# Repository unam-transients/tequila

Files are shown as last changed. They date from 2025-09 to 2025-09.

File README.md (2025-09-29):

# TEQUILA

TEQUILA (Transient Event *Q*, *U*, and *I* Light Analyzer) is an innovative imaging polarimeter being developed for the second Nasmyth port of COLIBRÍ. The science goals include measuring the evolution of the polarization of the optical afterglow of GRBs and variability in the polarization of blazars.

The project is lead by [Noémie Globus](https://github.com/orgs/unam-transients/people/mahadanah) with technical assistance from [Alan Watson](https://github.com/orgs/unam-transients/people/alanwatsonatwork).

- [Issues](https://github.com/orgs/unam-transients/projects/8)
- Repositories:
  - [sangrita](https://github.com/unam-transients/sangrita)
  - [tcs](https://github.com/unam-transients/tcs)
  - [tequila](https://github.com/unam-transients/tequila)
  - [tequila-science-and-design](https://github.com/unam-transients/tequila-science-and-design)

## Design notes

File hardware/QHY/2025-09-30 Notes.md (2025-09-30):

# 2029-09-30 Notes

Alan (CU) and Noémie (Ensenada)

- Noémie connected the external power supply.
- Initially, Alan was only able to cool to about -2 C, however the airflow was impeded. With the airflow free, he was able to cool it to about -6 C.
- With no cooling but with the fan, the temperature is about 32 C. The previous day, without the fans, it was about 45 C.
- Noémie disconnected the camera and RPi as they were too hot. Her office is at about 30 C.

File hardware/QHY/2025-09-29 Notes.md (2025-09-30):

# 2025-09-29 Notes

Alan (CU) and Noémie (Ensenada) working with the RPi and the QHY sensor.

## USB Capacity

We had the USB flash drive connected to the blue USB3 bus. Whenever we connected the QHY sensor to the blue bus we had problems with the RPi. Specifically, Alan was no longer able to run command, and we were not able to connect by SSH. Alan suspects the current drawn by the QHY was sufficient that the USB memory no longer worked. We apparently fixed this by connecting the USB memory to the white USB2 bus.

We then connected an external USB hard drive to the RPi via the white USB2 bus. It was seen initially, but then was not visible to `fdisk -l`. Alan rebooted the RPi, and it did not come back up. After removing the hard disk, it came back without any problem.

The conclusion seems to be:
- The QHY camera cannot share the USB3 bus with the USB flash memory.
- The USB flash memory cannot share the USB2 bus with USB hard drive.

## Control

I was able to:

- Determine the identifiers of the connected cameras.
- Open the camera by identifier.
- Determine its format.
- Read the temperature and cooler power.
- Read a FITS file.

I was not able to cool it as the external power supply was not connected.

## Documentation

The manual seems to be incomplete. It seems best to read it in conjunction with the header files.

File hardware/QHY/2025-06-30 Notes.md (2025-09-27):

# 2025-06-30 Laboratory Session

Noémie, Alan

Noémie had the new QHY 1253P sensor package.

The sensor was not supplied with a power supply. There was an extension that ended in a car adapter. With David’s intervention, someone connected the car adapter to a 12V power supply using crocodile clips.
Noémie installed QHY’s EZCAP software on her Mac.

We opened the sensor. We set the TEC to 50% manually. The power supply read 0.83 A. Stabilized at -3.7 C. The ambient temperature was about 23 C.

We took images with different gains, and that seemed to work. This is our first-light image:

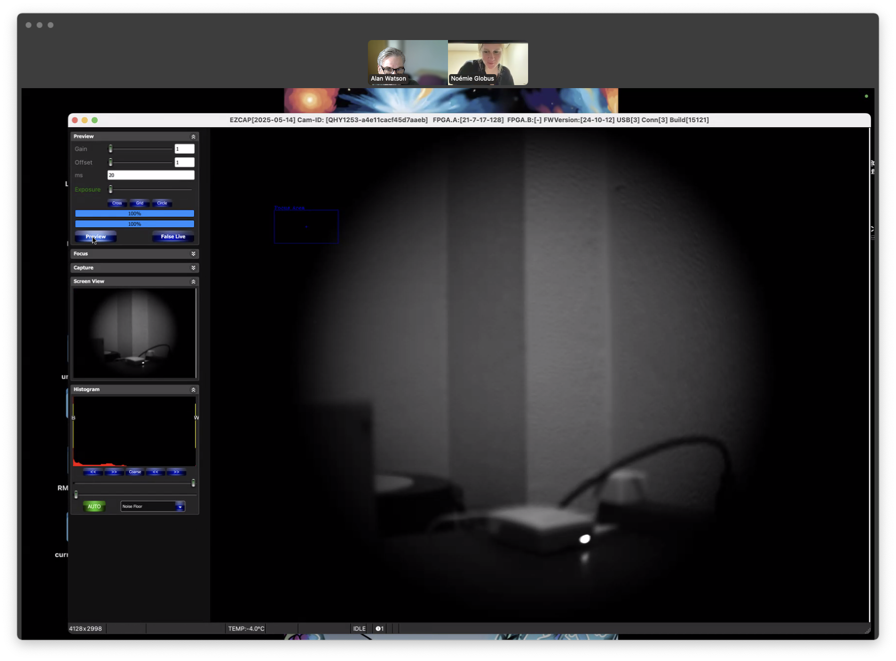
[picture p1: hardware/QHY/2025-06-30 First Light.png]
First-light image with the TEQUILA sensor First Light


We were able to set the temperature set point.

With TEC at 100%, the power supply read 1.67 A and the detector stabilized at -14.1 C.

We connected to the RPi. The sensor showed up as a “Cypress WestBridge”.

The housing has a ventilator.

We turned off the 12 V supply, but the sensor still appeared on the USB bus on the RPi.

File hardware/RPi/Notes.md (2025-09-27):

# Notes

2025-06-16: Alan sent Noémie a RPi 4 with 2 GB RB, 32 GB USB flash storage, and RPi USB-C power supply. The computer is on the UNAM Transients Tailscale VPN as "tequila-detector". It runs Ubuntu 24.04 LTS server.

2025-09-24: Alan gave Noémie a 1 TB external hard disk.

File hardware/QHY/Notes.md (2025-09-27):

# Notes

2025-05-23: Noémie ordered the detector using SCEECS funds at Stanford.

2025-06-17: Alan sent a Tamron 12VM1040ASIR 10-40 mm C-mount lens for the initial tests of the sensor.

2025-06-27: Noémie picked up the detector in LA.

2025-06-30: First light in the laboratory in Ensenada, running the QHY software on Noémie's Mac. Noémie was in the lab and Alan was on Zoom.

2025-06-30: Noémie bought a power supply from Amazon.

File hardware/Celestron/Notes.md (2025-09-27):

# Notes

Alan took one of the DDOTI adapters on 2025-09-23. It is currently in Mexico City. He has verified that it threads into the Edmund Optics T-mount separators.

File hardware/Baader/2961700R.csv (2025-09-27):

Baader SLOAN/SDSS r' Filter
λ (nm) | OD
200 | 7.404829948
201 | 6.487751797
202 | 6.695987374
203 | 7.385212657
204 | 7.253948757
205 | 7.143584362
206 | 6.735293259
207 | 6.944553319
208 | 6.797151173
209 | 7.076483743
210 | 6.867747845
211 | 7.202849989
212 | 6.919806970
213 | 7.006161490
214 | 6.950086375
215 | 6.819588336
216 | 6.937823771
217 | 7.101651772
218 | 6.793304495
219 | 7.013749629
220 | 7.234964484
221 | 6.895943519
222 | 6.952961717
223 | 6.993506486
224 | 7.009439787
225 | 6.943001524
226 | 6.986196389
227 | 6.937673117
228 | 7.035574262
229 | 7.124405156
230 | 6.837262205
231 | 6.933515886
232 | 6.949678127
233 | 7.054954803
234 | 6.914971177
235 | 7.134106375
236 | 7.035253280
237 | 6.855648408
238 | 6.903677095
239 | 7.026127530
240 | 7.037190999
241 | 6.995930179
242 | 6.940552731
243 | 7.073450381
244 | 6.975485587
245 | 7.025657044
246 | 7.000277144
247 | 6.953369057
248 | 7.009998378
249 | 7.190752040
250 | 7.058660273
251 | 6.967846107
252 | 6.937626206
253 | 7.127089643
254 | 6.897318147
255 | 7.002483836
256 | 6.921268666
257 | 7.187517399
258 | 6.982351557
259 | 6.927545176
260 | 6.996768497
261 | 7.022745706
262 | 7.000779786
263 | 6.960268142
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

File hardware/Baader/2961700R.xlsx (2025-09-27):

Baader SLOAN/SDSS r' Filter
l (nm) | OD
200 | 7.404829948
201 | 6.487751797
202 | 6.695987374
203 | 7.385212657
204 | 7.253948757
205 | 7.143584362
206 | 6.735293259
207 | 6.944553319
208 | 6.797151173
209 | 7.076483743
210 | 6.867747845
211 | 7.202849989
212 | 6.919806970
213 | 7.006161490
214 | 6.950086375
215 | 6.819588336
216 | 6.937823771
217 | 7.101651772
218 | 6.793304495
219 | 7.013749629
220 | 7.234964484
221 | 6.895943519
222 | 6.952961717
223 | 6.993506486
224 | 7.009439787
225 | 6.943001524
226 | 6.986196389
227 | 6.937673117
228 | 7.035574262
229 | 7.124405156
230 | 6.837262205
231 | 6.933515886
232 | 6.949678127
233 | 7.054954803
234 | 6.914971177
235 | 7.134106375
236 | 7.035253280
237 | 6.855648408
238 | 6.903677095
239 | 7.026127530
240 | 7.037190999
241 | 6.995930179
242 | 6.940552731
243 | 7.073450381
244 | 6.975485587
245 | 7.025657044
246 | 7.000277144
247 | 6.953369057
248 | 7.009998378
249 | 7.190752040
250 | 7.058660273
251 | 6.967846107
252 | 6.937626206
253 | 7.127089643
254 | 6.897318147
255 | 7.002483836
256 | 6.921268666
257 | 7.187517399
258 | 6.982351557
259 | 6.927545176
260 | 6.996768497
261 | 7.022745706
262 | 7.000779786
263 | 6.960268142
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

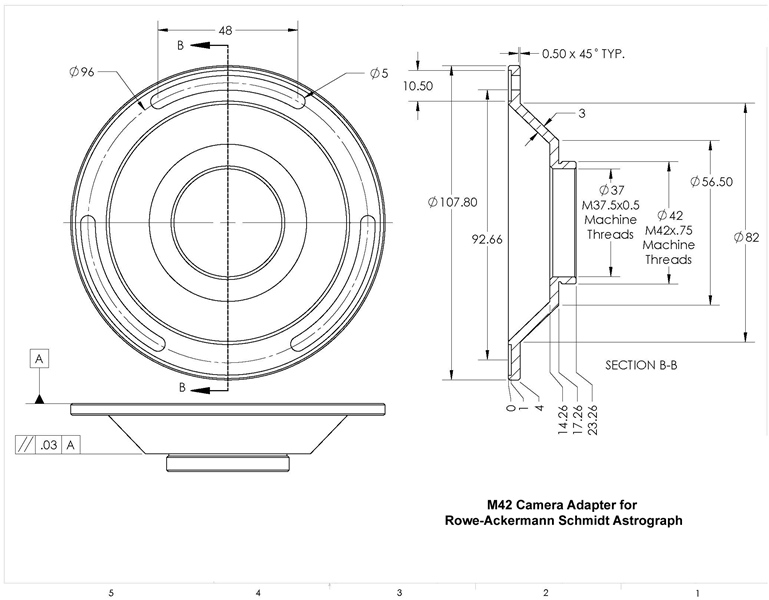
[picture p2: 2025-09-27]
hardware/Celestron/celestron-rasa-to-t-adapter.jpg

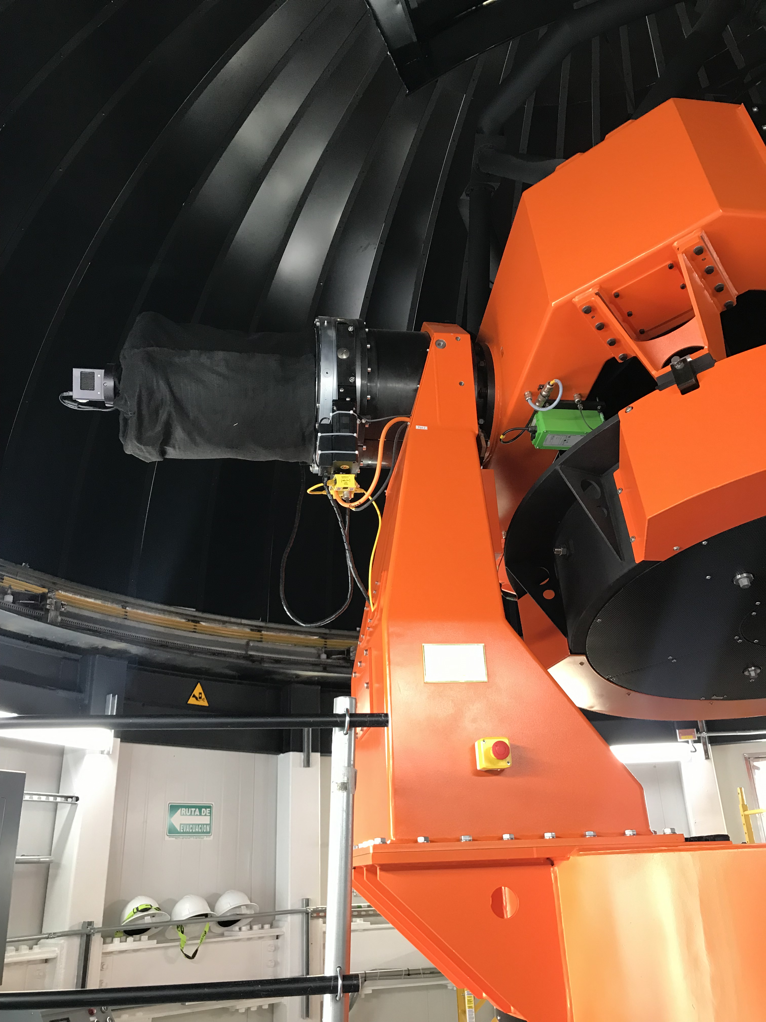
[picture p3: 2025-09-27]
hardware/OGSE/2025-09-23 OGSE.jpg

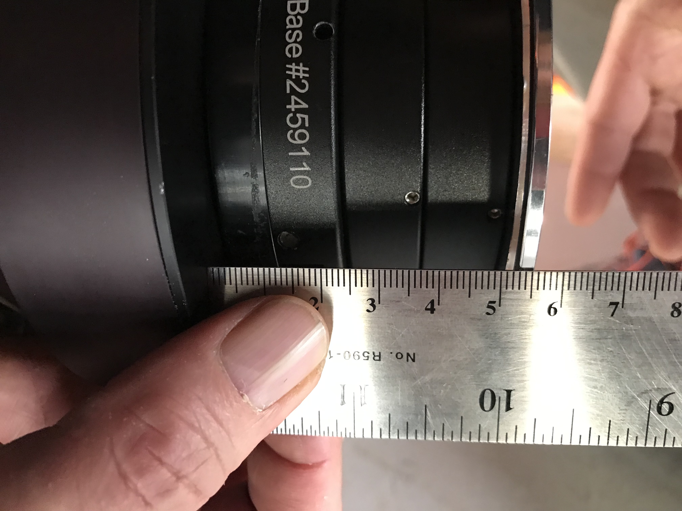
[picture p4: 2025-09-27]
hardware/OGSE/2025-09-23 OGSE FLI detector extension.jpg

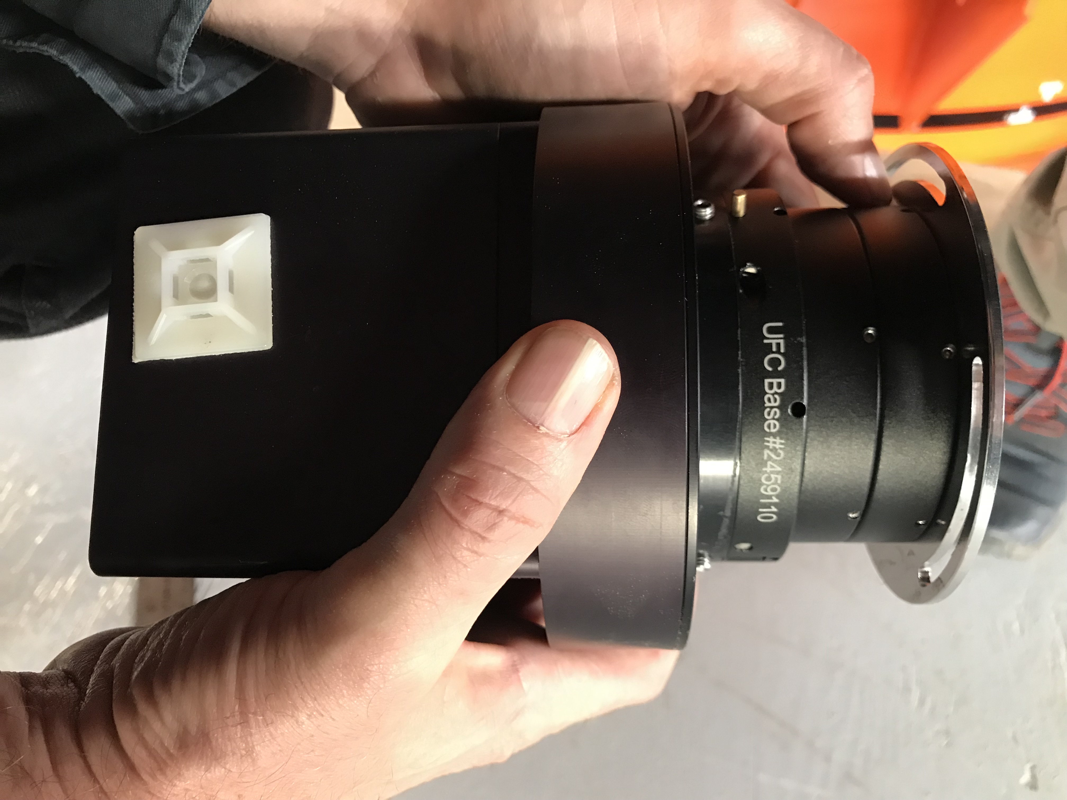
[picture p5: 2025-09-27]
hardware/OGSE/2025-09-23 OGSE FLI detector.jpg

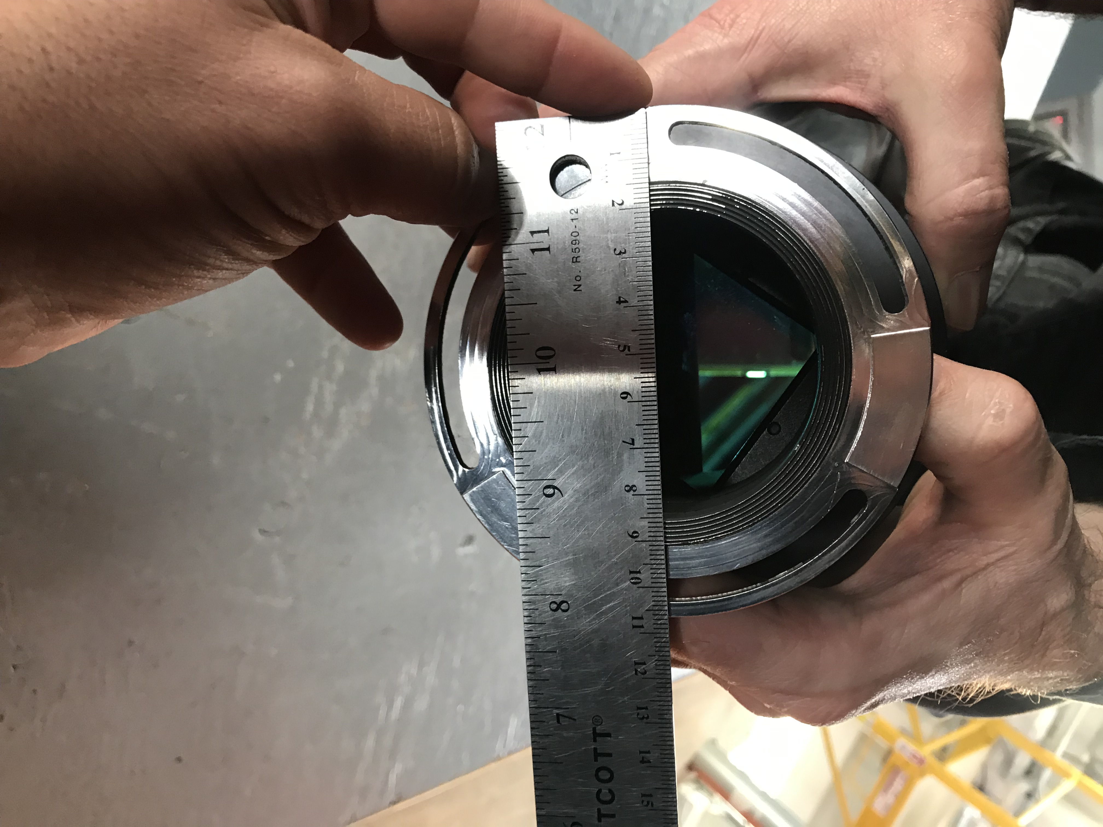
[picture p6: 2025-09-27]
hardware/OGSE/2025-09-23 OGSE FLI detector aperture.jpg

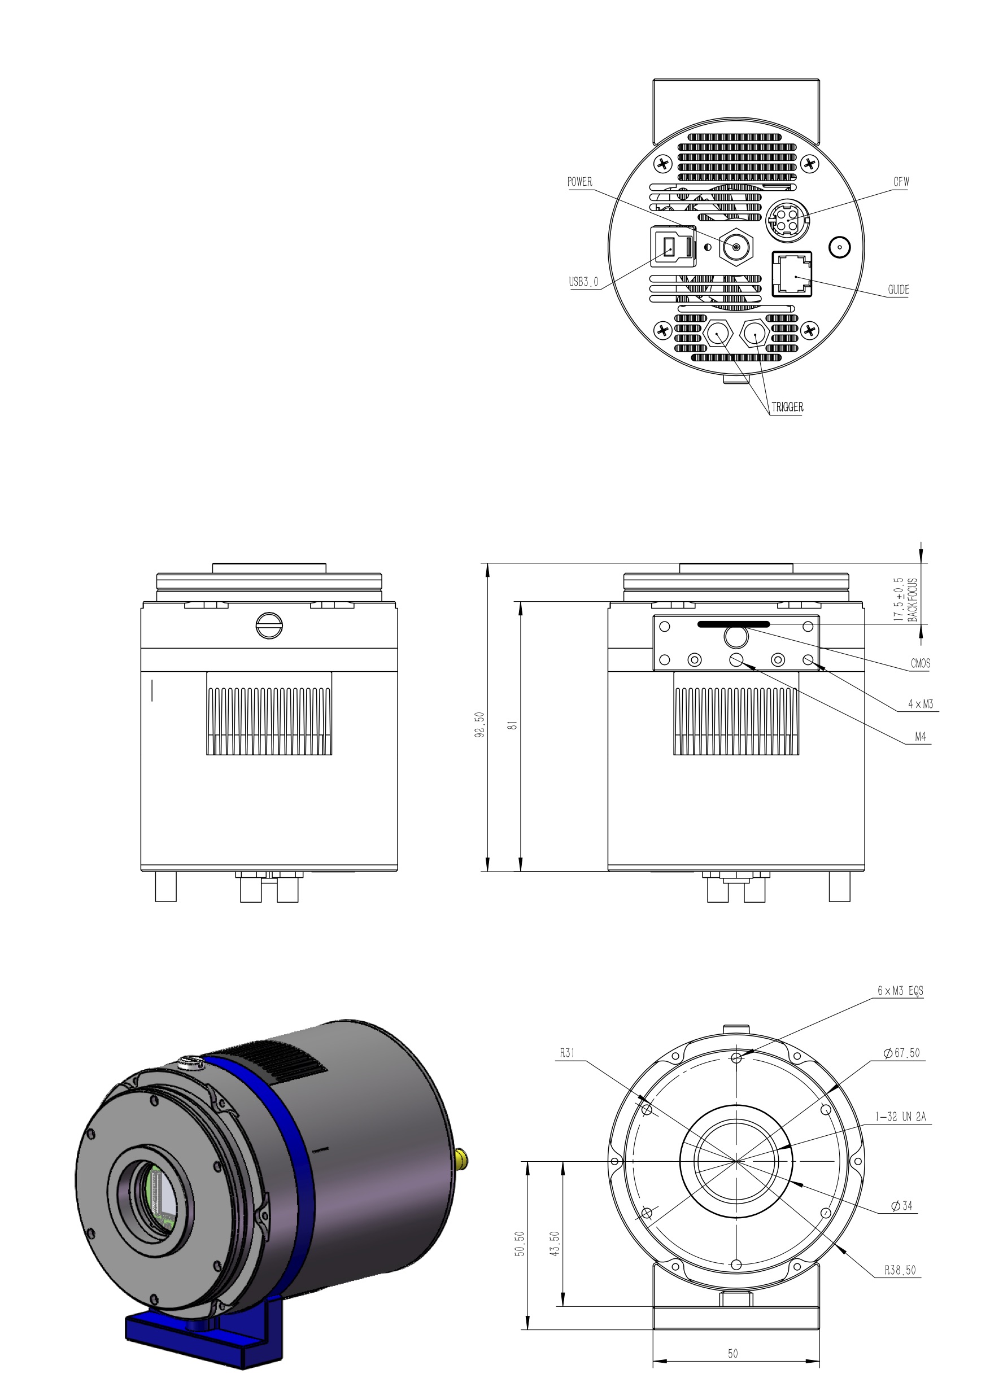
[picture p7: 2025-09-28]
hardware/QHY/QHY 1253P Mechanical Drawings.jpg

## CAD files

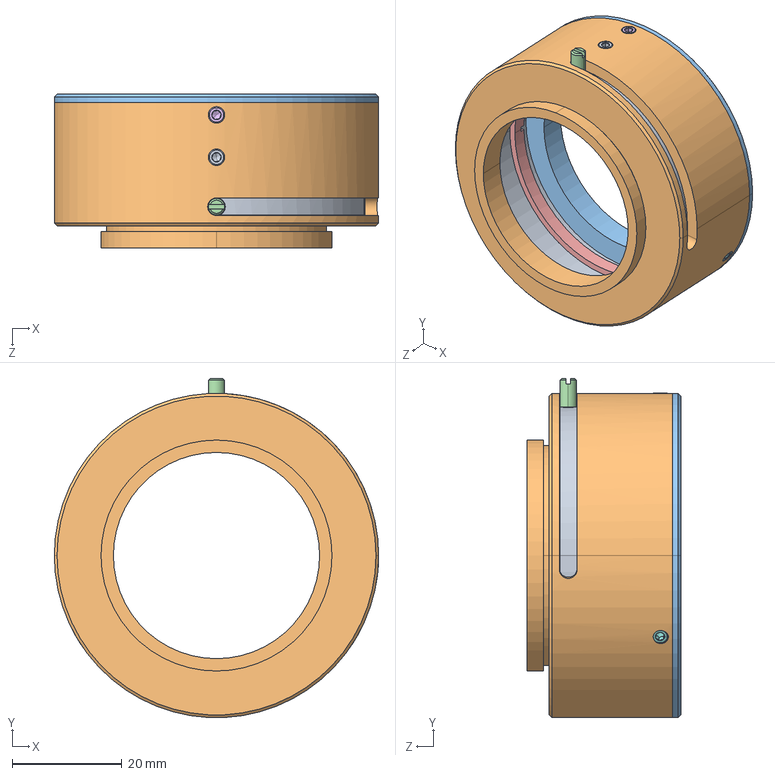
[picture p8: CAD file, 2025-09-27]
hardware/Edmund Optics/11147/step_11147.step
59.0 x 61.7 x 28.0 mm

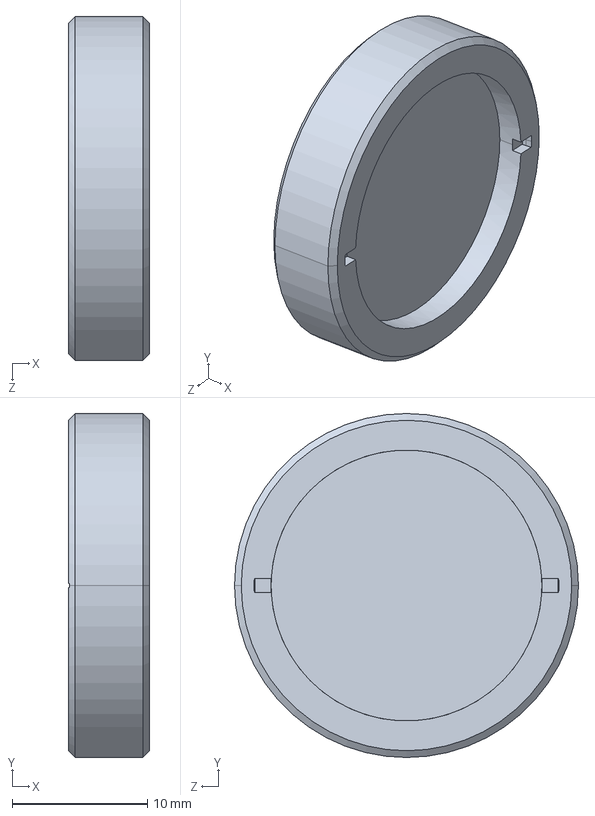
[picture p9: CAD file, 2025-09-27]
hardware/Edmund Optics/39038/step_39038.step
6.00 x 25.4 x 25.4 mm

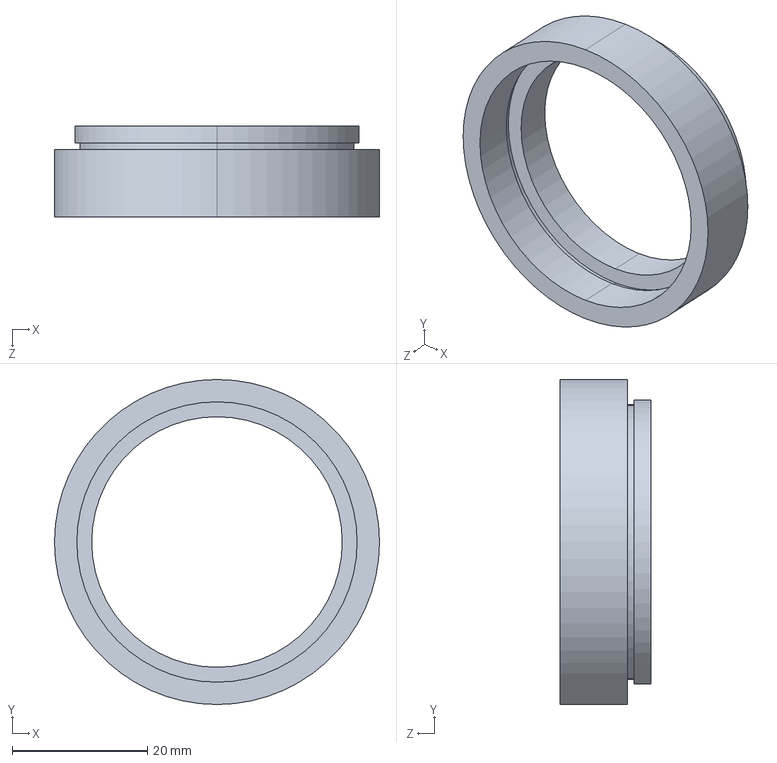
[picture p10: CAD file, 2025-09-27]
hardware/Edmund Optics/52294/step_52294.step
48.0 x 48.0 x 13.5 mm

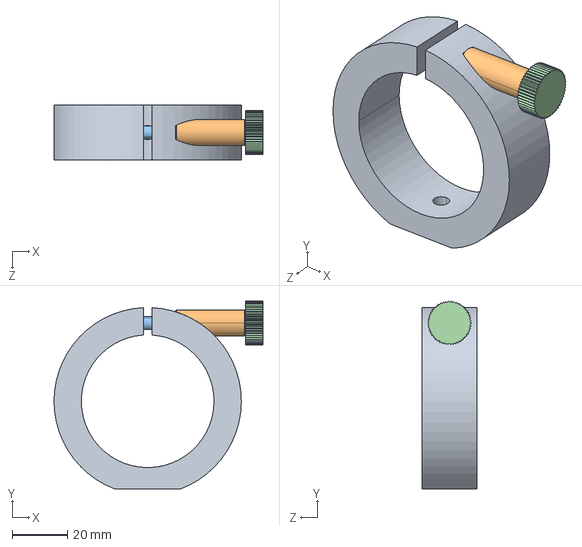
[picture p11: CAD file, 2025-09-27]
hardware/Edmund Optics/52304/step_52304.step
75.8 x 68.2 x 19.9 mm

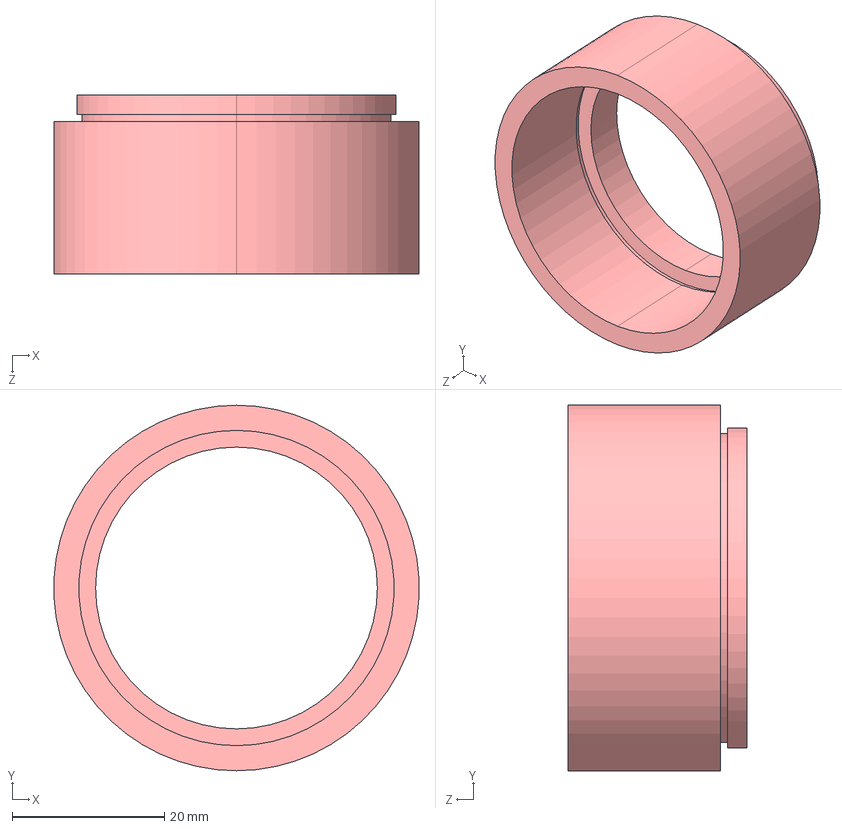
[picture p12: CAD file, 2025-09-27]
hardware/Edmund Optics/53231/iges_53231.igs
47.9 x 48.0 x 23.5 mm

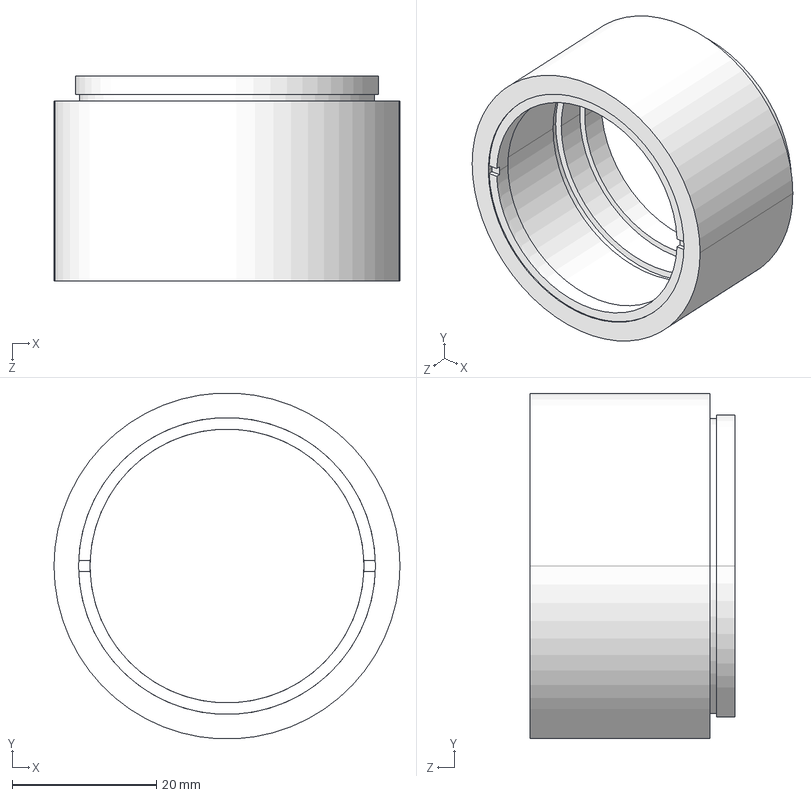
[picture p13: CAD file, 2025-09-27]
hardware/Edmund Optics/57978/iges_57978.igs
48.0 x 47.9 x 28.5 mm

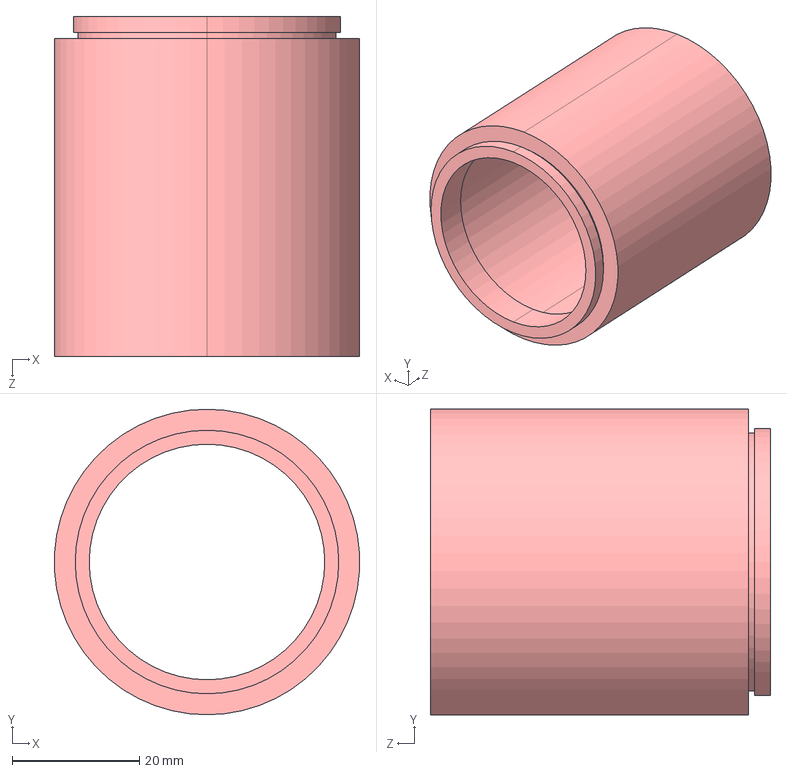
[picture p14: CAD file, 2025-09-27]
hardware/Edmund Optics/58735/iges_58735.igs
47.9 x 48.0 x 53.5 mm

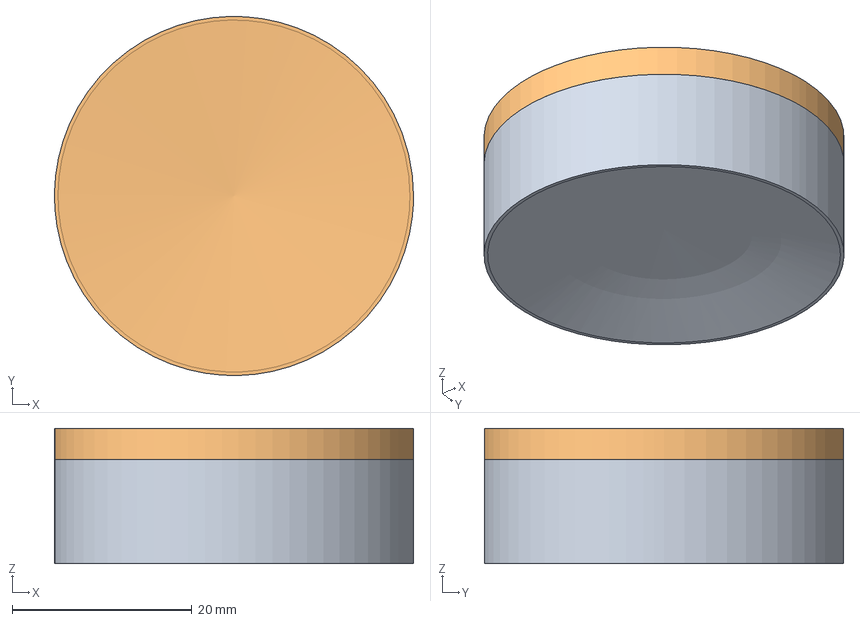
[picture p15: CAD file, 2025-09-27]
hardware/Edmund Optics/63765/iges_63765.igs
40.0 x 40.0 x 15.1 mm

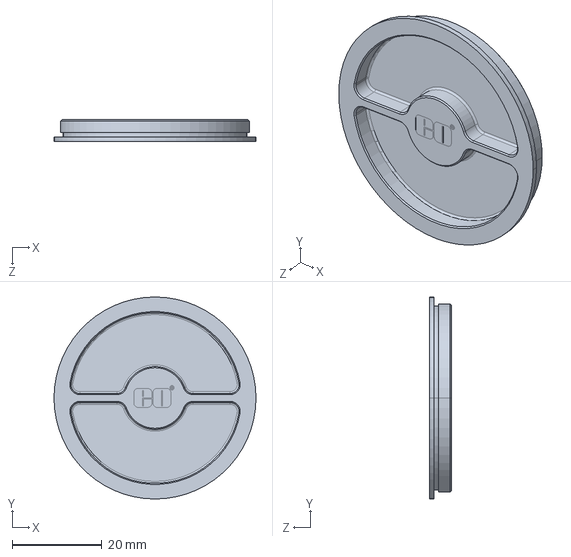
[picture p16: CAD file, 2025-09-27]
hardware/Edmund Optics/66037/step_66037.step
45.0 x 45.0 x 5.00 mm

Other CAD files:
hardware/Edmund Optics/39039/step_39039.step
hardware/Edmund Optics/11147/iges_11147.igs
hardware/Edmund Optics/39038/iges_39038.igs
hardware/Edmund Optics/39039/iges_39039.igs
hardware/Edmund Optics/52294/iges_52294.igs
hardware/Edmund Optics/52304/iges_52304.igs
hardware/Edmund Optics/53231/step_53231.step
hardware/Edmund Optics/57978/step_57978.step
hardware/Edmund Optics/58735/step_58735.step
hardware/Edmund Optics/63765/step_63765.stp
hardware/Edmund Optics/66037/iges_66037.igs

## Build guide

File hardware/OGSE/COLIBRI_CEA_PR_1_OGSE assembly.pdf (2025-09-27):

Ref : COLIBRI_CEA_PR_1_OGS E assembly

Ed. : | 1
Rev. : | 1
Date: | 20/10/2020 | Page : 1/21

OGSE mounting and dismounting procedure for all configuration

Prepared by | Signature | Verified by | Signature
F. Dolon
S. Ronayette
Document under Configuration Control | Approval request
Approved by | Function | Signature
S. Basa | PI F-GFT

Summary

Annexes

Keywords

Distribution | See Distribution list at the end of this document

Rev. : | 1
Date: | 20/10/2020 | Page : 2/21

Document Change Record

Edition | Revision | Date | Modified pages | Observations
1 | 0 | 23/07/2019 | ALL | First version
1 | 1 | 20/10/2020 | 3, 5 | Updated CAD views with the new assembly, following visit at OHP in August 2020

Rev. : | 1
Date: | 20/10/2020 | Page : 3/21

## TABLE OF CONTENT

### 8. PROCEDURE OF ASSEMBLY AND INSTALLATION ON THE TELESCOPE OF THE HARTMAN

## TABLE OF FIGURE

Rev. : | 1
Date: | 20/10/2020 | Page : 4/21

Rev. : | 1
Date: | 20/10/2020 | Page : 5/21

### 1. GENERAL ASPECT

### 1.1. Scope of the document

This document explains step by step the mounting, the dismounting of the OGSE and its installation on the balancing tool. It explains also the assembly of all tests configuration and their assembly on the OGSE.

### 1.2. Applicable documents

Applicable Documents (AD)

AD | Title | Reference | Version
1 | OGSE Interfaces plates 2D drawing | COLIBRI_CEA_MAM_2_OGSE Interfaces plates 2D drawing | 1.0
2 | OGSE 3D Mounting configuration | COLIBRI_CEA_MAM_1_OGSE 3D Mounting configuration.STEP | 1.0
3 | OGSE 2D DrawingCounterweight | COLIBRI_OHP_DRW_1_OGSE 2D drawing_Counterweight | 1.0
4 | OGSE 2D Drawing_MainStructure | COLIBRI_OHP_DRW_1_OGSE 2D Drawing_MainStruct | 1.0
5 | OGSE 3D Design 30-09-19 | COLIBRI_OHP_MAM_1_OGSE 3D Design 30-09-19.STEP | 2.0
6 | Hartman mask 3D drawing | COLIBRI_OHP_MAM_3_Hartman mask 3D drawing | 1.0
7 | Hartman mask 2D drawing | COLIBRI_OHP_DRW_4_Hartman mask 2D drawing | 1.0

### 1.3. Reference documents

Reference Documents (RD)

RD | Title | Reference | Version

Rev. : | 1
Date: | 20/10/2020 | Page : 6/21

### 2. OGSE MOUNTING PROCEDURE

2.1. 3D view of the OGSE
[AD3], [AD4] and [AD5] present the 2D drawing and the 3D design of the OGSE.
Figure 1 shows the OGSE without and with counterweight. The test instrument will be placed on the central ring of the main structure.

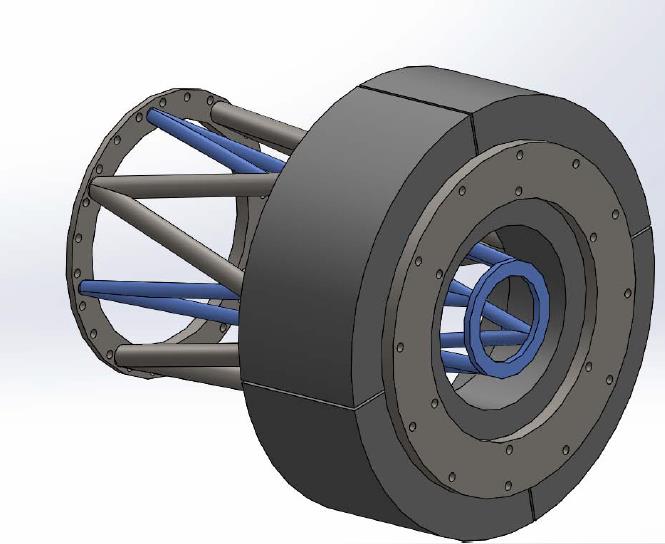
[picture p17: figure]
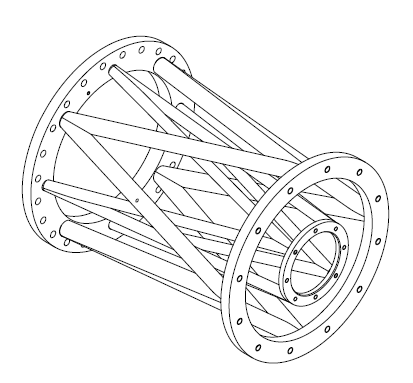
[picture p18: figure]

Main structure without counterweight | Main structure with counterweight

Figure 1: 3D View of the OGSE

### 2.2. Dimension

Weight≈ 350kg
- Circular counterweight: 5.072kg
- Lateral counterweight: 3.02kg
Overall dimensions:
- Length: 525.5mm
- Diameterwithoutlateral counterweight: 480mm
- Diameter with lateral counterweight: 620mm

### 2.3. List of material

- OGSE parts: main structure, counterweights: circular (x10) and lateral (x80)
- M12 threaded stems x12short (length: 175mm)
- M12 threaded stems x12 long (length: 250mm)
- M12x40 hexagonal head screws x24
- Flat key or socket spanner of 19

Rev. : | 1
Date: | 20/10/2020 | Page : 7/21

### 2.4. Procedure of mounting step by step

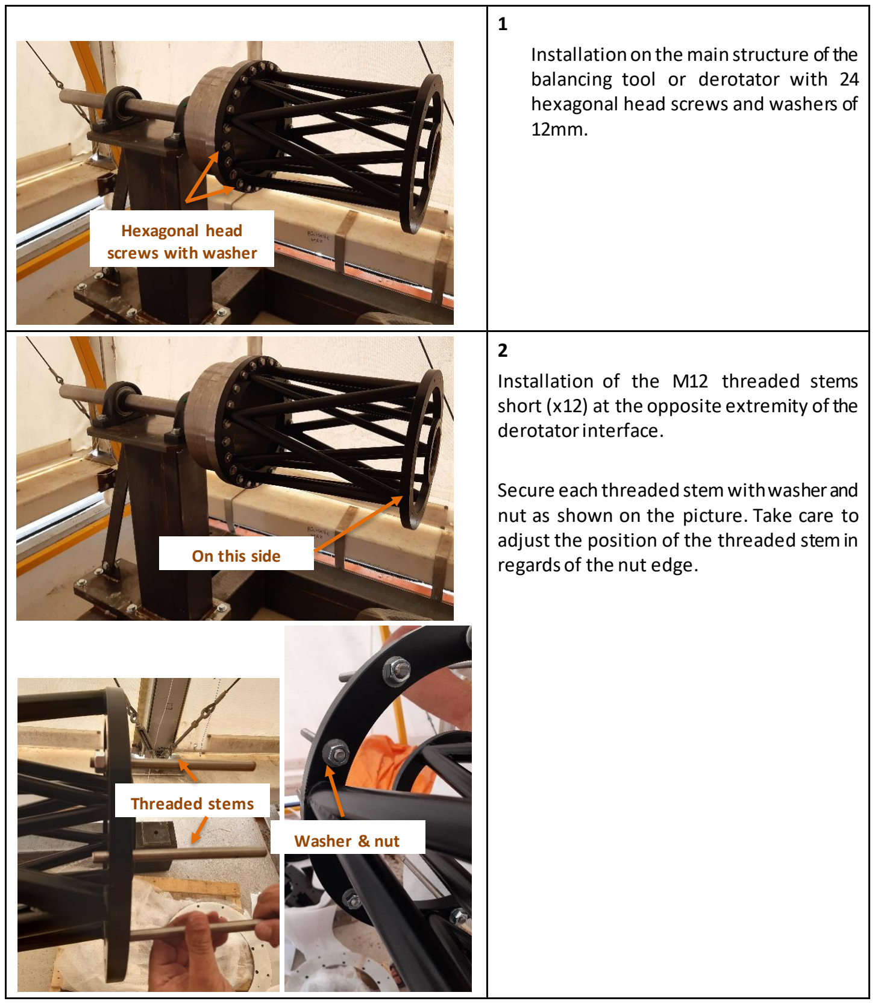
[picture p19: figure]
balancing tool or derotator with 24 hexagonal head screws and washers of 12mm.; Installation of the M12 threaded stems; derotator interface.; regards of the nut edge.; Hexagonal head screws with washer; On this side; Threaded stems; Washer & nut

Installation on the main structure ofthe

short (x12) at the opposite extremity of the

Secure each threaded stemwith washer and nut as shown on the picture. Take care to adjust the position of the threaded stem in

Rev. : | 1
Date: | 20/10/2020 | Page : 8/21

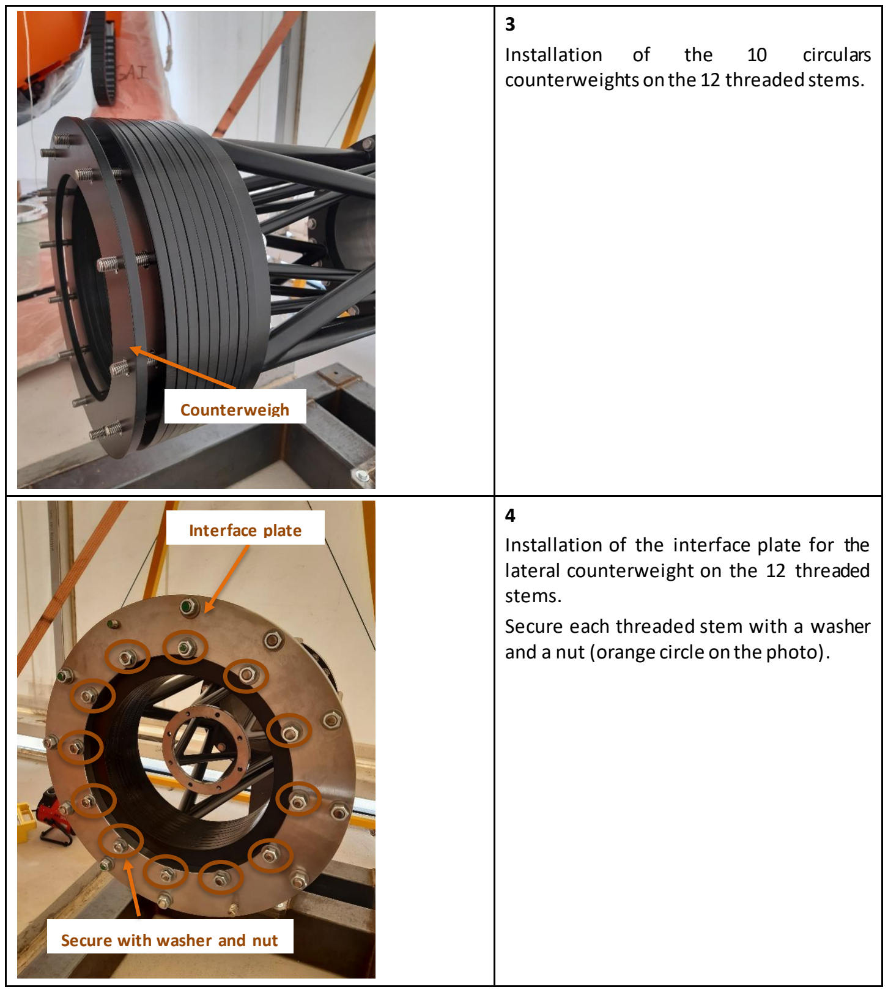
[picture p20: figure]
Installation; the; circulars; stems.; Secure each threaded stem with a washer and a nut (orange circle on the photo).; Counterweigh; Interface plate; Secure with washer and nut

counterweights on the 12 threaded stems.

Installation of the interface plate for the lateral counterweight on the 12 threaded

Rev. : | 1
Date: | 20/10/2020 | Page : 9/21

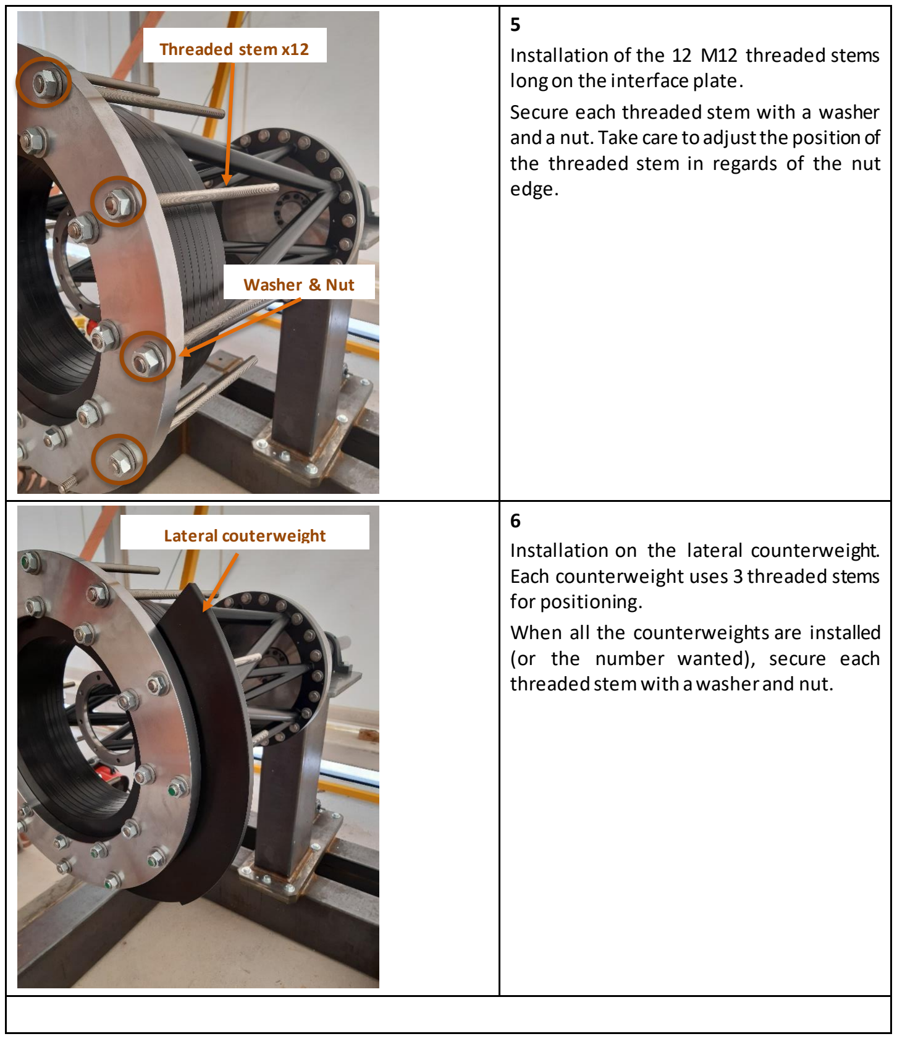
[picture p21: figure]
long on the interface plate.; Secure each threaded stem with a washer; the threaded stem in regards of the nut edge.; 6 Installation on the lateral counterweight.; for positioning.; (or the number wanted), secure each threaded stem with a washer and nut.; Threaded stem x12; Lateral couterweight; Washer & Nut

Installation of the 12 M12 threaded stems

and a nut. Take care to adjust the position of

Each counterweight uses 3 threaded stems

When all the counterweights are installed

Rev. : | 1
Date: | 20/10/2020 | Page : 10/21

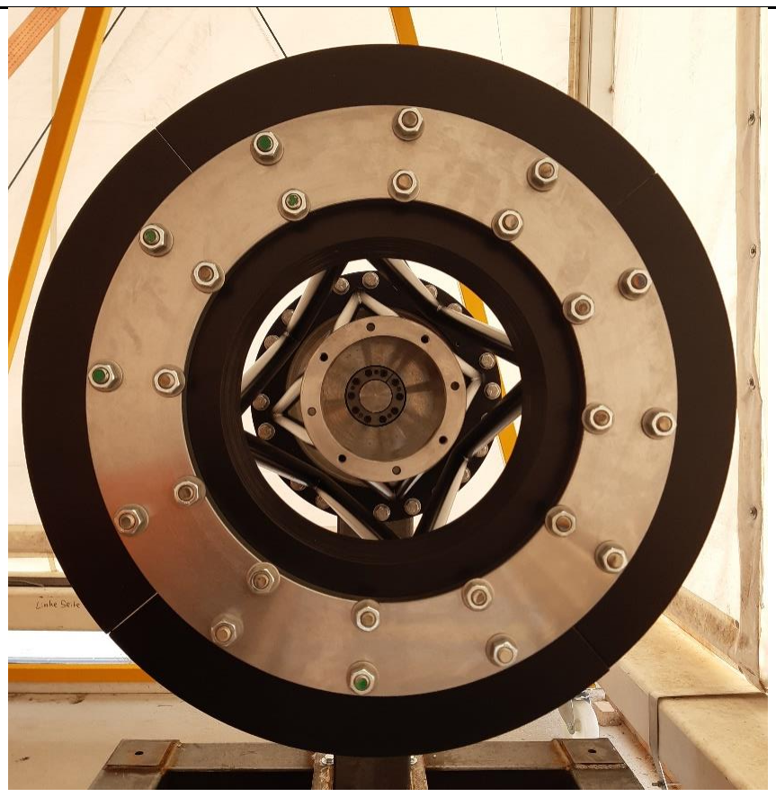
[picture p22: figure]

Installation of the OGSE finished on the balancing tool.

### 2.5. Procedure of dismounting

1
Two threaded holes can be used to help the dismounting ofthe OGSE from the derotator interface if needed.

To dismount the counterweight just follow

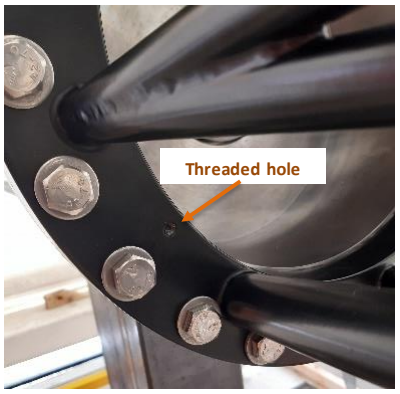
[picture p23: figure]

the procedure starting by the last step. Threaded hole

Rev. : | 1
Date: | 20/10/2020 | Page : 11/21

Before installation, each mounting shall be balanced with the balancing tool. Once balanced, the OGSE is directly mount on the derotator.

### 3. TEST CCD1 MOUNTING PROCEDURE

3.1. 3D view of the CCD1 configuration
[AD1] and [AD2] present the 3D design and the 2D drawing of the different configurations of tests. Figure 2 shows the configuration of the CCD1 test.

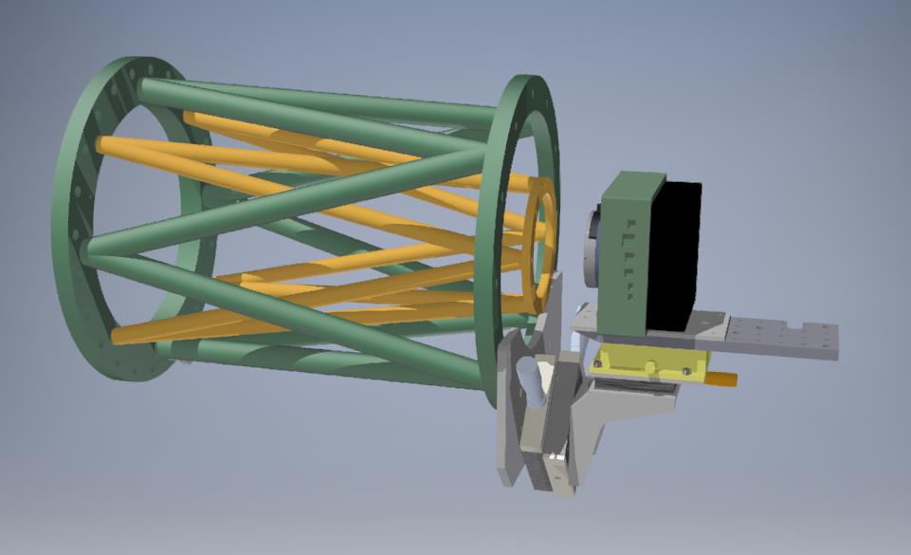
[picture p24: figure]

Figure 2: 3D view of the CCD1 test configuration

### 3.2. Procedure of mounting step by step of the CCD1 configuration

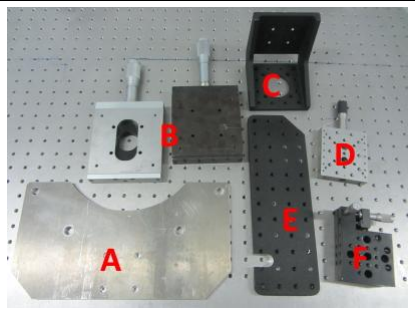
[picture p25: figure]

1
Required parts:
A. Custom I/F plate
B. Microcontrol large translation stages (x2)
C. Square bracket EQ-120-I
D. Microcontrol small translation stage
E. Newport small table
F. Newport tip-tilt platform M-36

Rev. : | 1
Date: | 20/10/2020 | Page : 12/21

2 Mount the square bracket on the first large translation stage (4x M5 screws + nuts and washers)

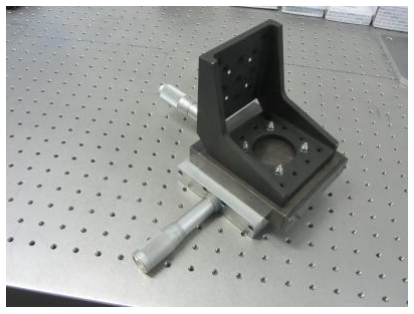
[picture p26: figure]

3 Mount the second large translation stage underneath (4x M5 screws)

4 Mount the custom interface plate (4x M5 screws) and the lowest and decentered holes

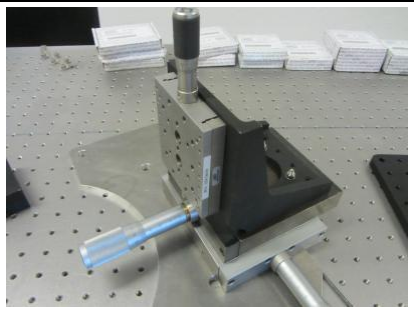
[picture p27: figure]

5 Mount the small translation stage on the square bracket

Rev. : | 1
Date: | 20/10/2020 | Page : 13/21

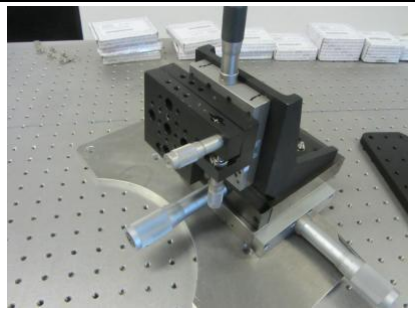
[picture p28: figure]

6 Mount the tip-tilt platform, using three M6 screws

7 Mount the small table, using the set of four counter-bored clear holes.

8 Mount the FLI camera on its interface plate

9 Mount the camera on the table

10 Mount the assembly on the OGSE structure (outer ring – no counterweights) The assembly must be used with an angle between -90° and 0° (see photo)

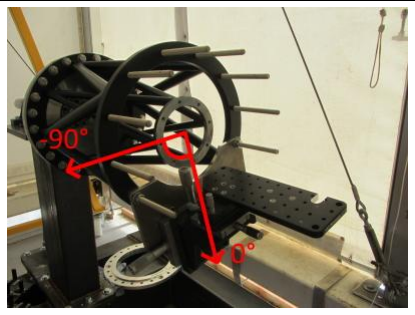
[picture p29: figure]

### 3.3. Configuration of the counterweight

This test configuration is balanced using the following counterweight configuration: TBW

### 4. TEST CCD2 MOUNTING PROCEDURE

4.1. 3D view of the CCD2 configuration

Rev. : | 1
Date: | 20/10/2020 | Page : 14/21

[AD1] and [AD2] present the 3D design and the 2D drawing of the different configurations of tests. Figure 3 shows the configuration of CCD2 test.

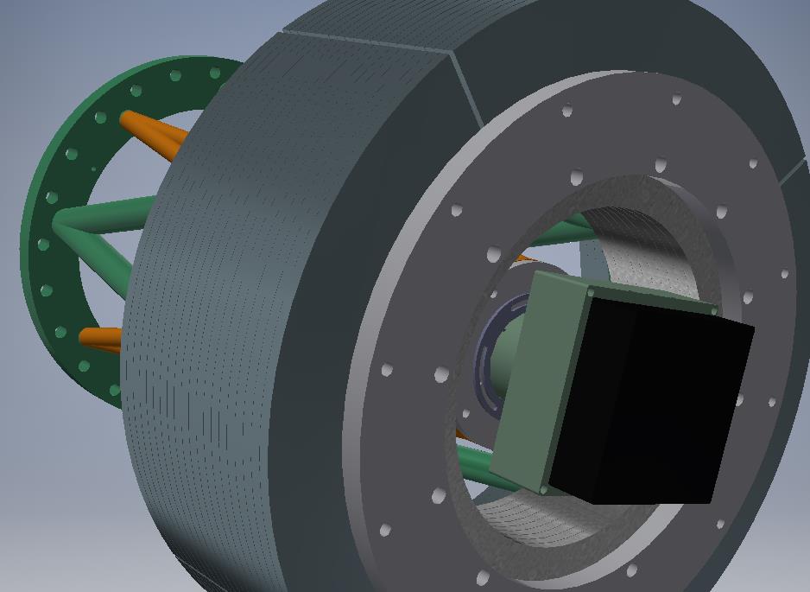
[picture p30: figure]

Figure 3: 3D view of the CCD2 test configuration

### 4.1. Procedure of mounting step by step of the CCD2 configuration

### 1 Required parts:

A. Custom I/F plate
B. Telescope adapter plate
C. 40mm extension
D. 5mm extension
E. Filter holder with FLI camera adapter

Rev. : | 1
Date: | 20/10/2020 | Page : 15/21

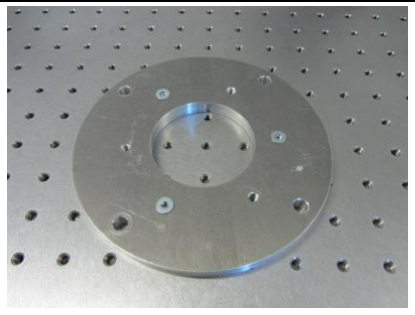
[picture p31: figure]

2 Place three M4 washer of the IF plate

3 Mount the telescope adapter plate

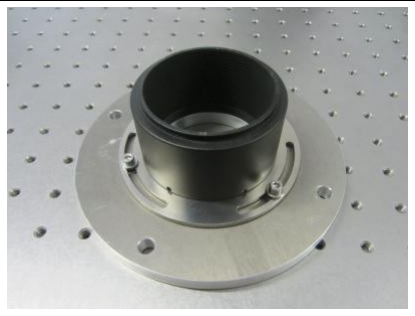
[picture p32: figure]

4 Mount an extension tube (nominally: 40mm)

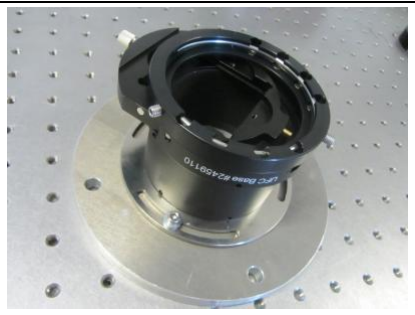
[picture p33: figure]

5 Mount the fliter holder

6 Mount the FLI camera

Rev. : | 1
Date: | 20/10/2020 | Page : 16/21

7
Mount on OGSE using four M8 screws (inner ring, counter weights in place)

### 4.2. Configuration of the counterweight

This test configuration is balanced using the following counterweight configuration:

### 5. TEST HASO MOUNTING PROCEDURE

5.1. 3D view of the HASO configuration
[AD1] and [AD2] present the 3D design and the 2D drawing of the different configurations of tests. Figure 4 shows the configuration of the HASO test.

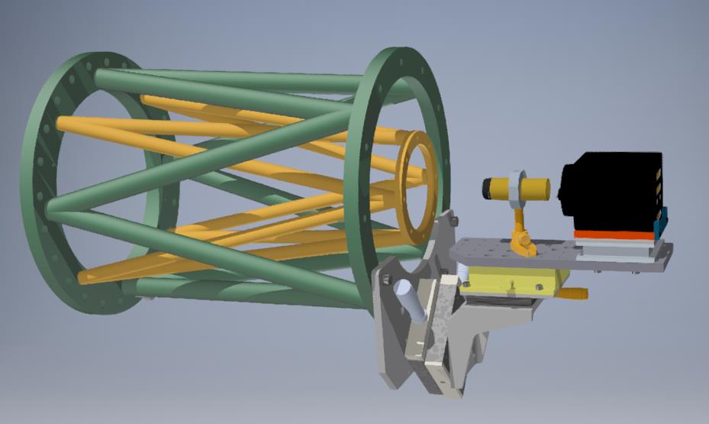
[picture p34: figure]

Figure 4: 3D view of the HASO test configuration (TBD)

### 5.2. Procedure of mounting step by step of the HASO configuration

TBW | 1

Rev. : | 1
Date: | 20/10/2020 | Page : 17/21

### 5.3. Configuration of the counterweight

This test configuration is balanced using the following counterweight configuration: TBW

### 6. TEST LASER MOUNTING PROCEDURE

6.1. 3D view of the laser configuration
[AD1] and [AD2] present the 3D design and the 2D drawing of the different configurations of tests. Figure 5 shows the configuration of the laser test.

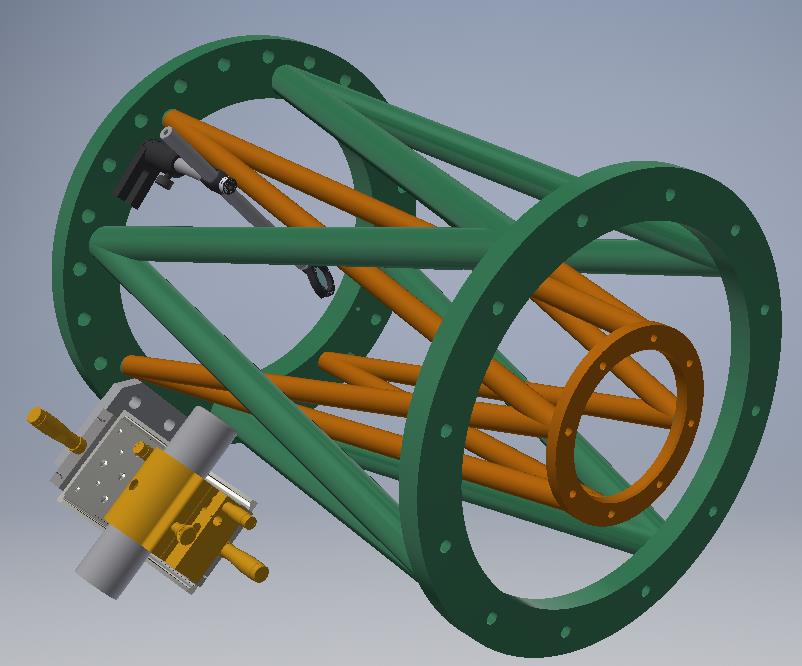
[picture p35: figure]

Figure 5: 3D view of the laser test configuration

### 6.2. Procedure of mounting step by step of the laser configuration

Rev. : | 1
Date: | 20/10/2020 | Page : 18/21

1 Required parts A. Beam splitter holder B. Pedestal for beam splitter holder C. Laser on 4 DOF platform D. Custom I/F plate

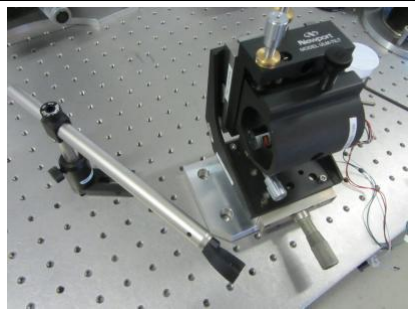
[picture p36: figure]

2 Mount I/F plate underneath the laser platform (note: only 3 out of 4 screws can be mounted) Mount beam splitter holder in pedestal

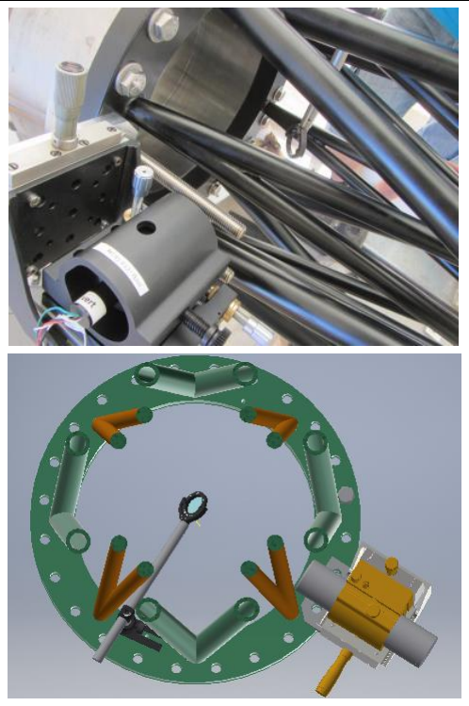
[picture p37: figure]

3
Mount both assembly on the OGSE, at the derotator exit side.
The beam splitter is mounted using on the M6 threaded holes
For the laser, unscrew two M12 bolts that are used for attaching the OGSE, place the laser I/F plate, and re-screw the bolts. Note: longer M12 screws are necessary.

The CAD view shows the relative position of the beam-splitter holder and the laser.

### 6.3. Configuration of the counterweight

This test configuration is balanced using the following counterweight configuration:

Rev. : | 1
Date: | 20/10/2020 | Page : 19/21

### 7. TEST MANTA MOUNTING PROCEDURE

7.1. 3D view of the Manta configuration
[AD1] and [AD2] present the 3D design and the 2D drawing of the different configurations of tests. Figure 6 shows the configuration of the manta camera test.

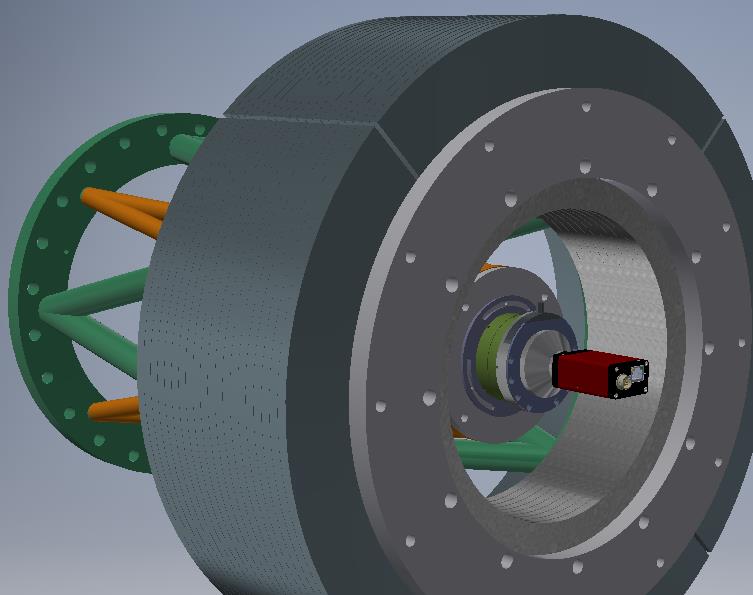
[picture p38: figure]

Figure 6: 3D view of the Manta camera test configuration

### 7.2. Procedure of mounting step by step of the Manta configuration

### 1 Required parts

A. I/F plate with telescope adapter and extension tube (follow step 1 to 4 of procedure 4.1 “CCD2 configuration”)
B. Filter holder with T2 adapter
C. T2 to C-mount adapter

Rev. : | 1
Date: | 20/10/2020 | Page : 20/21

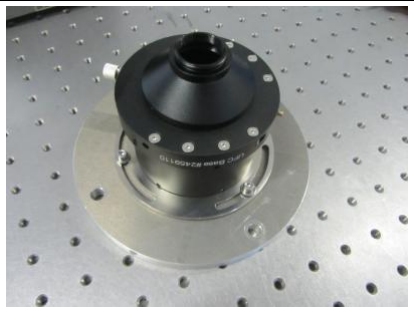
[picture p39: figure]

2 Mount the filter holder on the extension tube, then screw the T2 to C-mount adapter.

3 Mount the assembly on the OGSE using four M8 screws (inner ring, counter weights in place)

### 7.3. Configuration of the counterweight

This test configuration is balanced using the following counterweight configuration: TBW

### 8. PROCEDURE OF ASSEMBLY AND INSTALLATION ON THE TELESCOPE OF THE

HARTMAN MASK

8.1. 3D view of the Hartman mask
[AD6] and [AD7] present the 3D design and the 2D drawing of the Hartman mask.
Figure 7 shows the mask and its installation on the telescope.

Rev. : | 1
Date: | 20/10/2020 | Page : 21/21

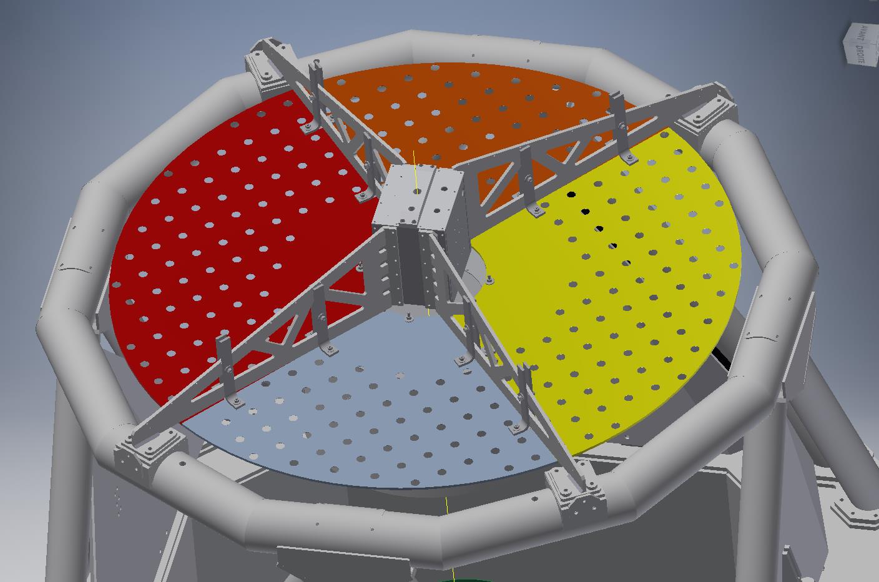
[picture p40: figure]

Figure 7: 3D view of the Hartmann mask on the telescope

TBW | 1

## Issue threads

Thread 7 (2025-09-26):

Mark the rotating mounts

alanwatsonatwork, 2025-09-26:
### Problem

The rotating mounts are not calibrated in angle. We need to mark them at 0, 5, 10, ..., 90 degrees.

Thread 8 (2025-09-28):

Add quotation for QHY sensor

alanwatsonatwork, 2025-09-28:
### Problem

The quotation for the QHY sensor is not in the repository.

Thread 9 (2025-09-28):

Add information on the power supply for the detector

alanwatsonatwork, 2025-09-28:
### Problem

Noémie bought a power supply for the QHY detector (from Amazon?). We need to add information on it.

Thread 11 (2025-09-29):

Send temperature sensor to Ensenada

alanwatsonatwork, 2025-09-29:
### Problem

_No response_

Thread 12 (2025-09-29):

Install temperature sensor on RPi

alanwatsonatwork, 2025-09-29:
### Problem

_No response_

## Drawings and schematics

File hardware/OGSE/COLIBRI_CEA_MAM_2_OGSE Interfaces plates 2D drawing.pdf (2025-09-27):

D | D

168,0

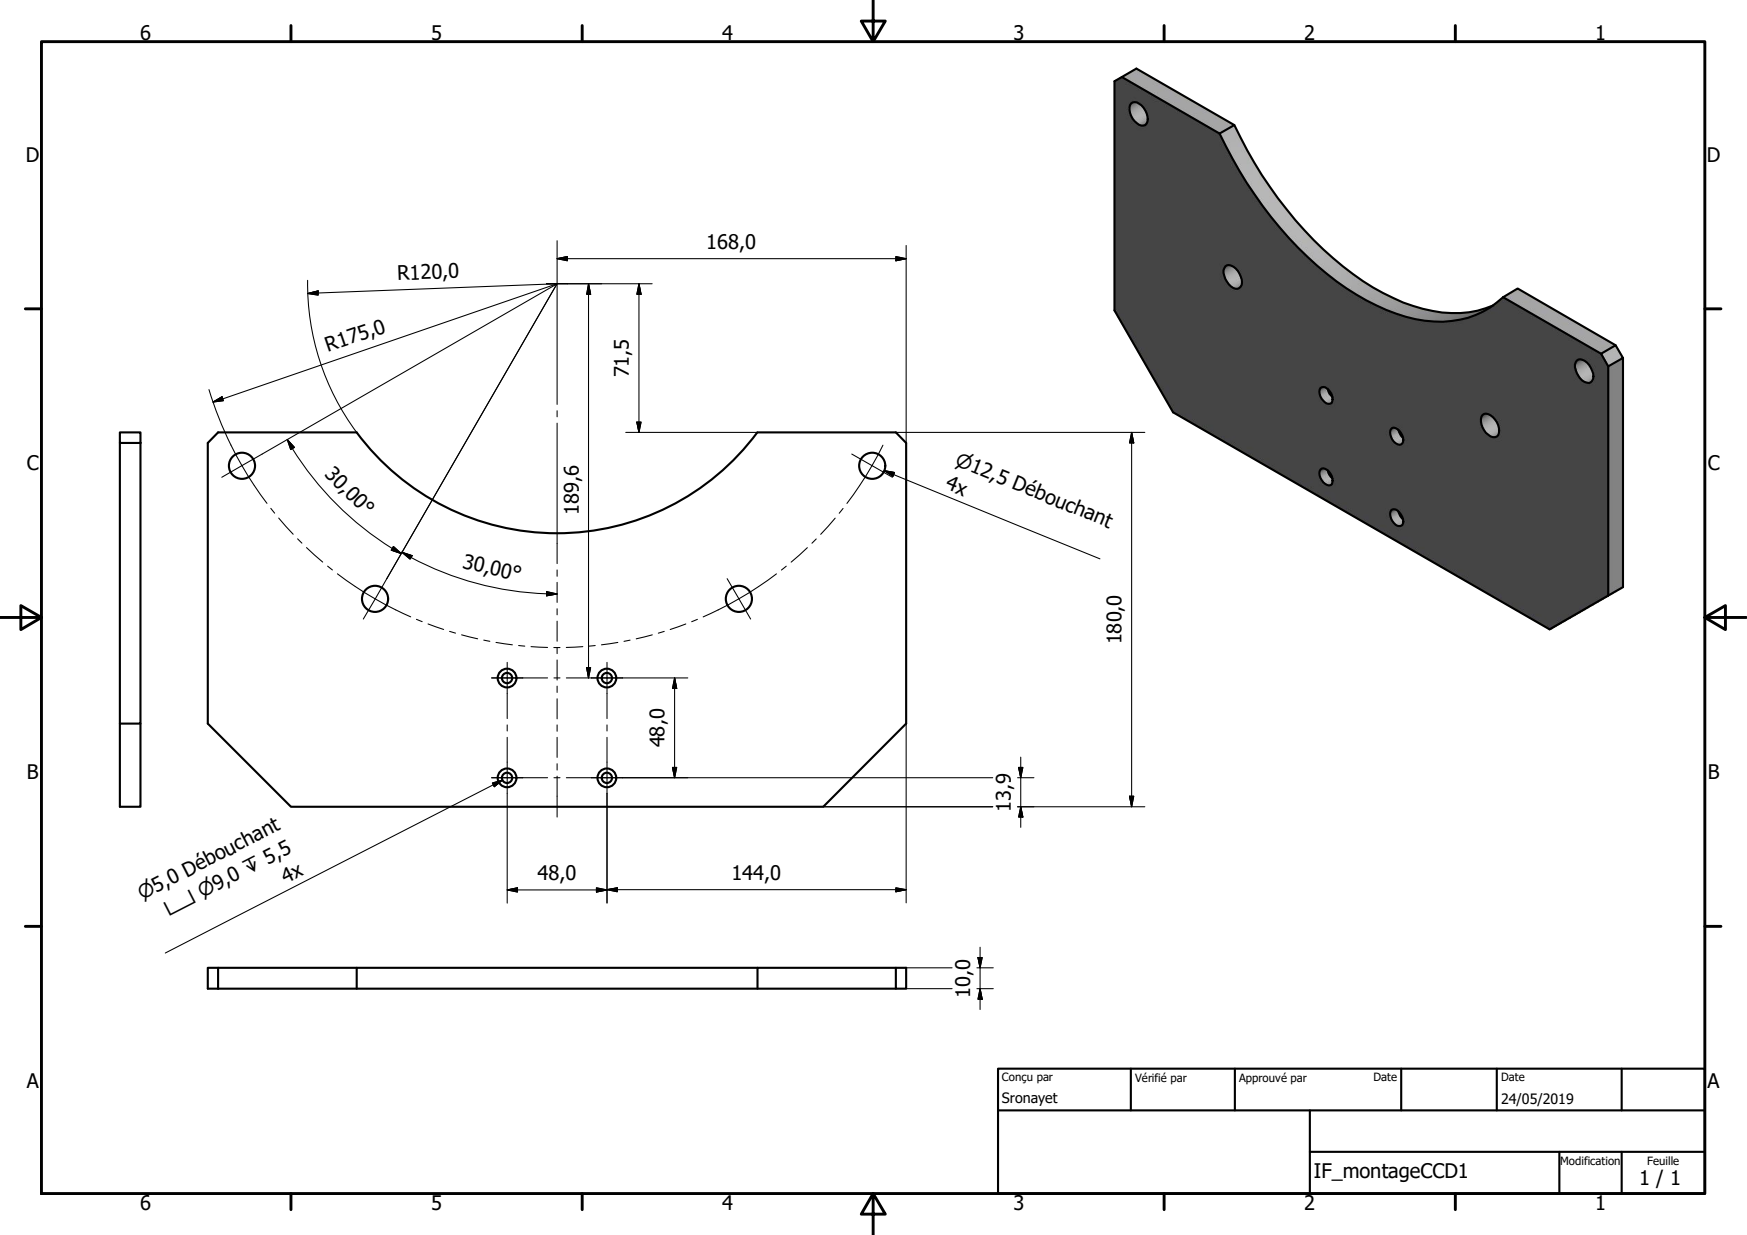
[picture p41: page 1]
IF_montageCCD1; Sronayet; Conou par; Vprifip par; Approuvp par; Date; Modification; Feuille; P12,5 Dpbouchant 4x; P5,0 Dpbouchant X P9,0 Z 5,5 4x

D | D

17,3

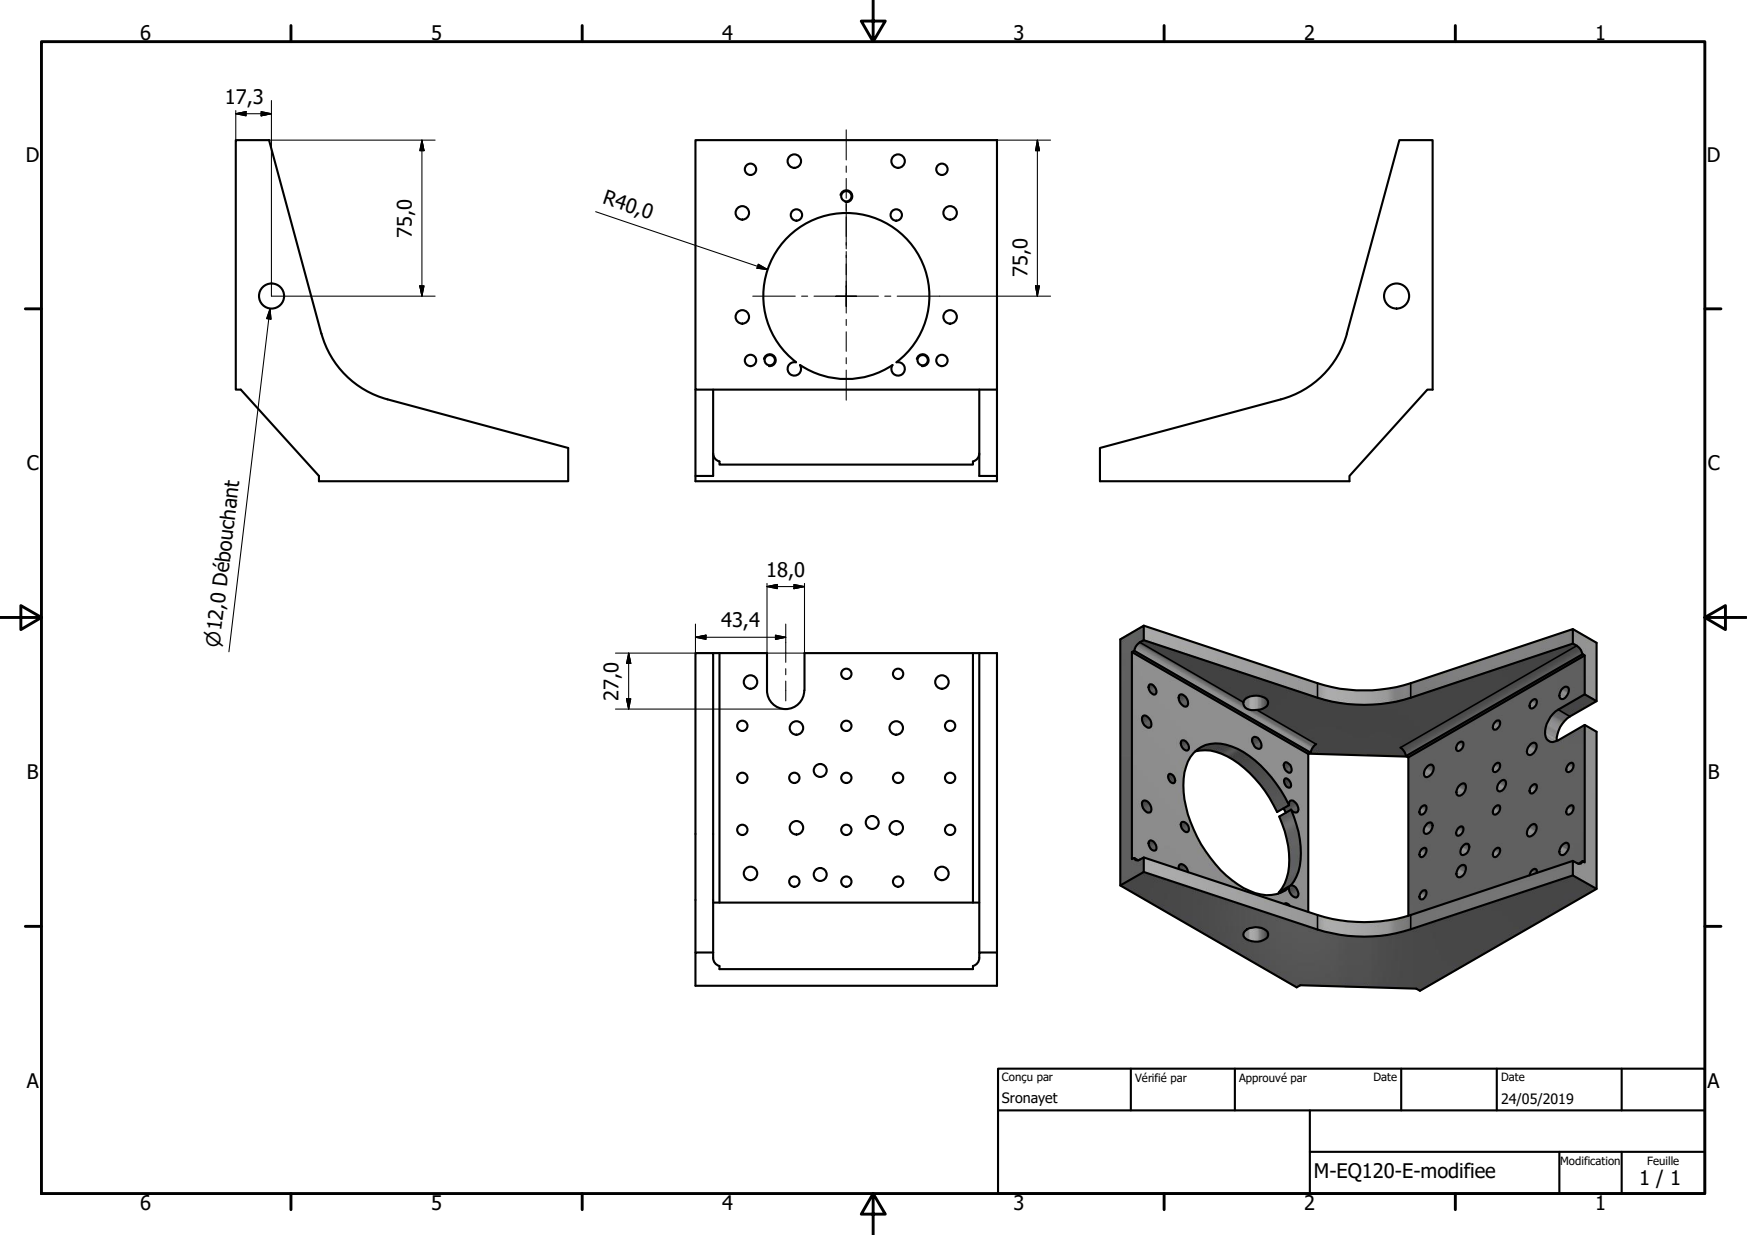
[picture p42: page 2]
M-EQ120-E-modifiee; Sronayet; Conou par; Vprifip par; Approuvp par; Date; Dpbo

D | D

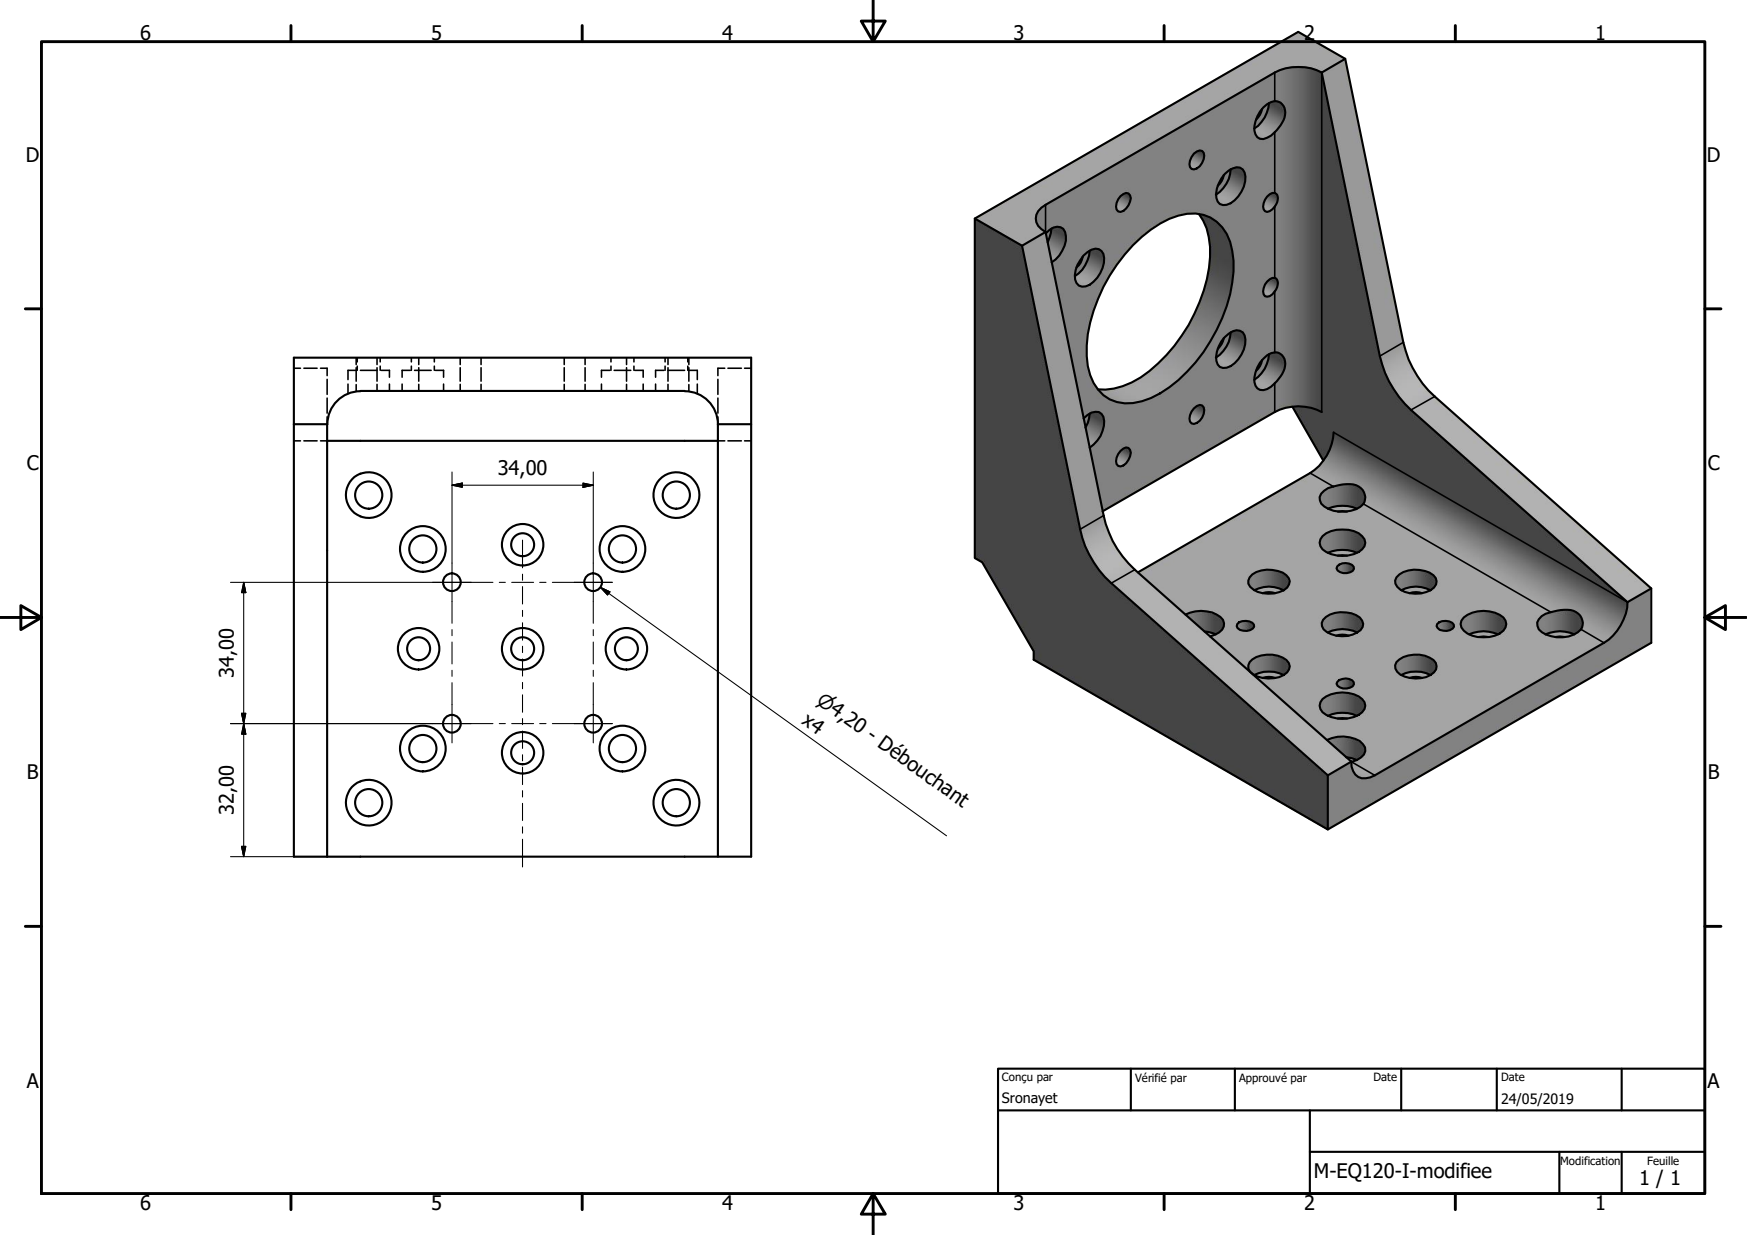
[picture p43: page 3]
M-EQ120-I-modifiee; Sronayet; Conou par; Vprifip par; Approuvp par; Date; P4,20 - Dpbouchant x4

D | D

15,4

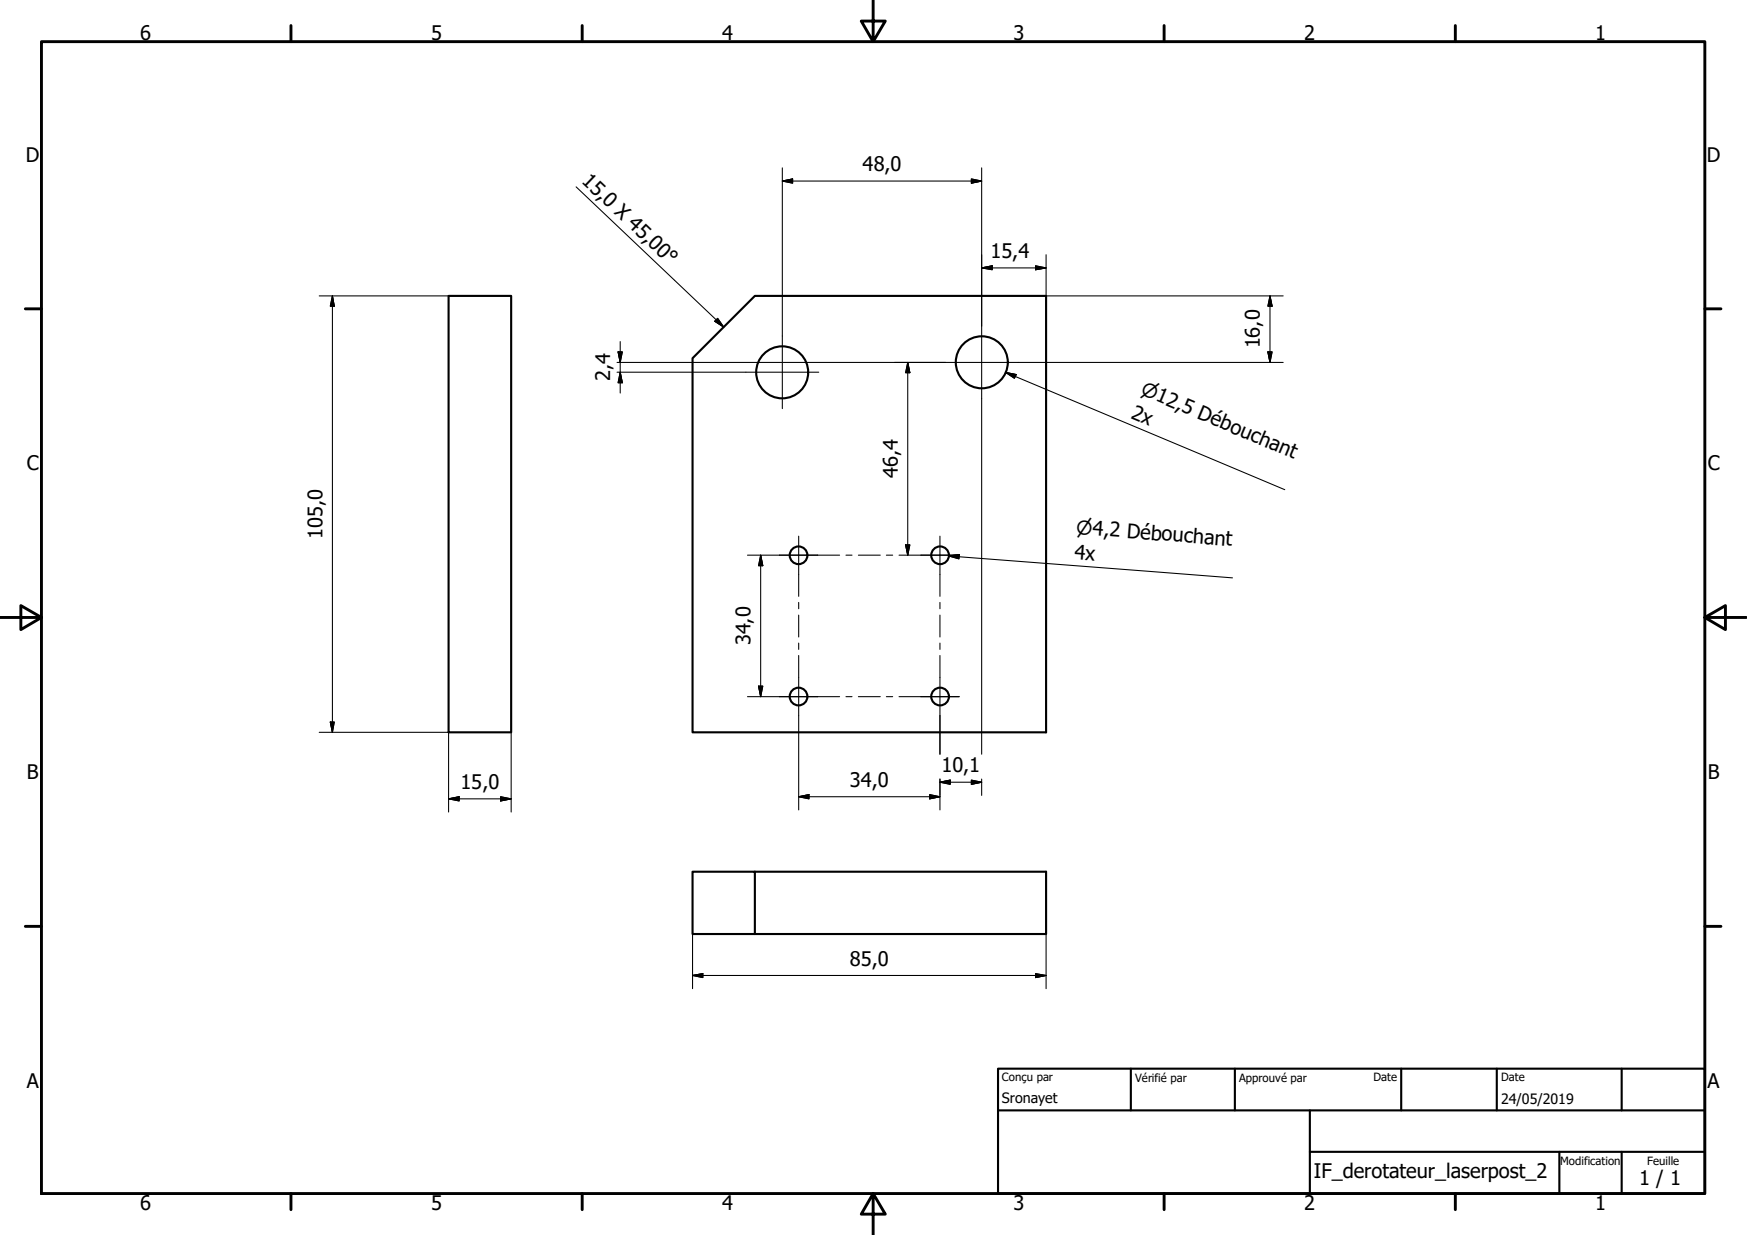
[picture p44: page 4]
IF_derotateur_laserpost_2; Sronayet; Conou par; Vprifip par; Approuvp par; Date; P12,5 Dpbouchant 2x; P4,2 Dpbouchant

D | D
10,0 | P¹⁴⁰,0

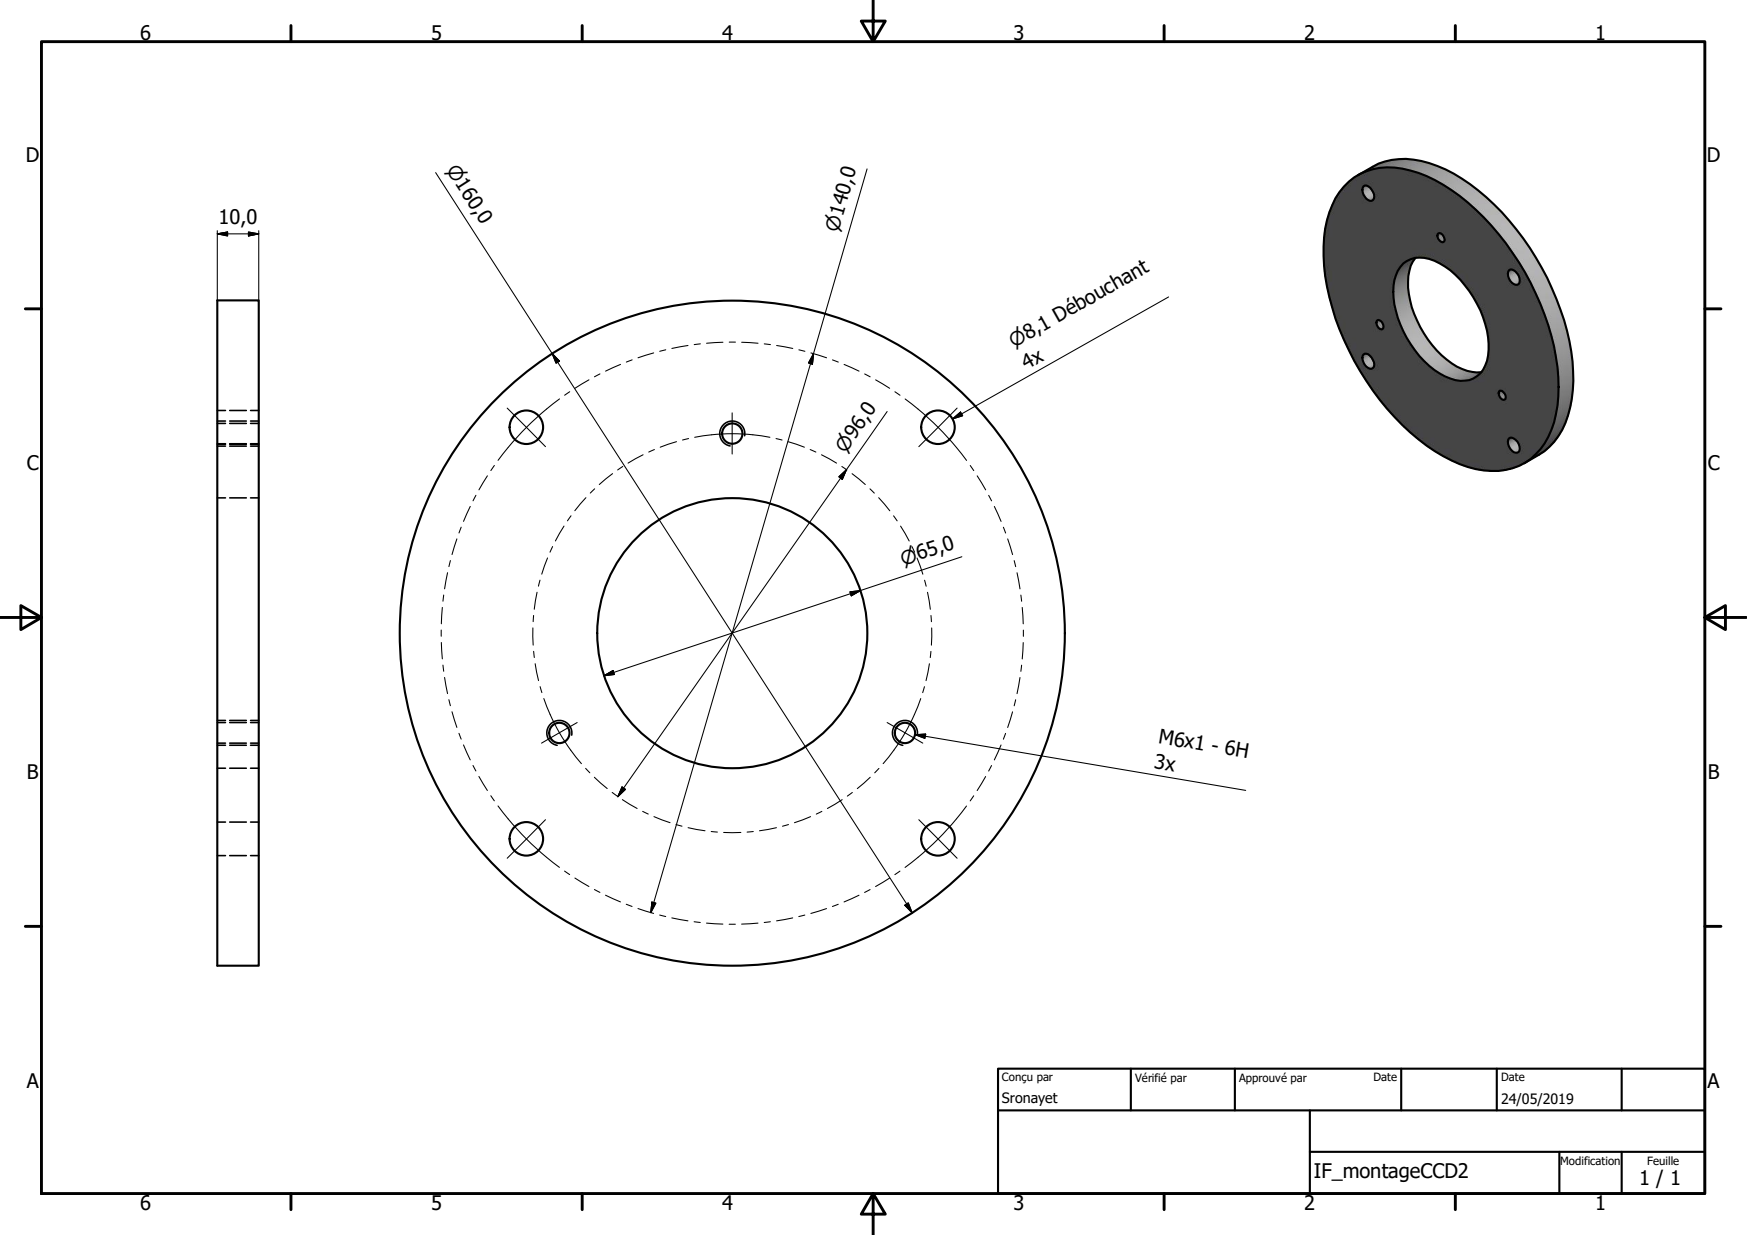
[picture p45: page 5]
IF_montageCCD2; Sronayet; Conou par; Vprifip par; Approuvp par; Date; P8,1 Dpbouchant

D | D

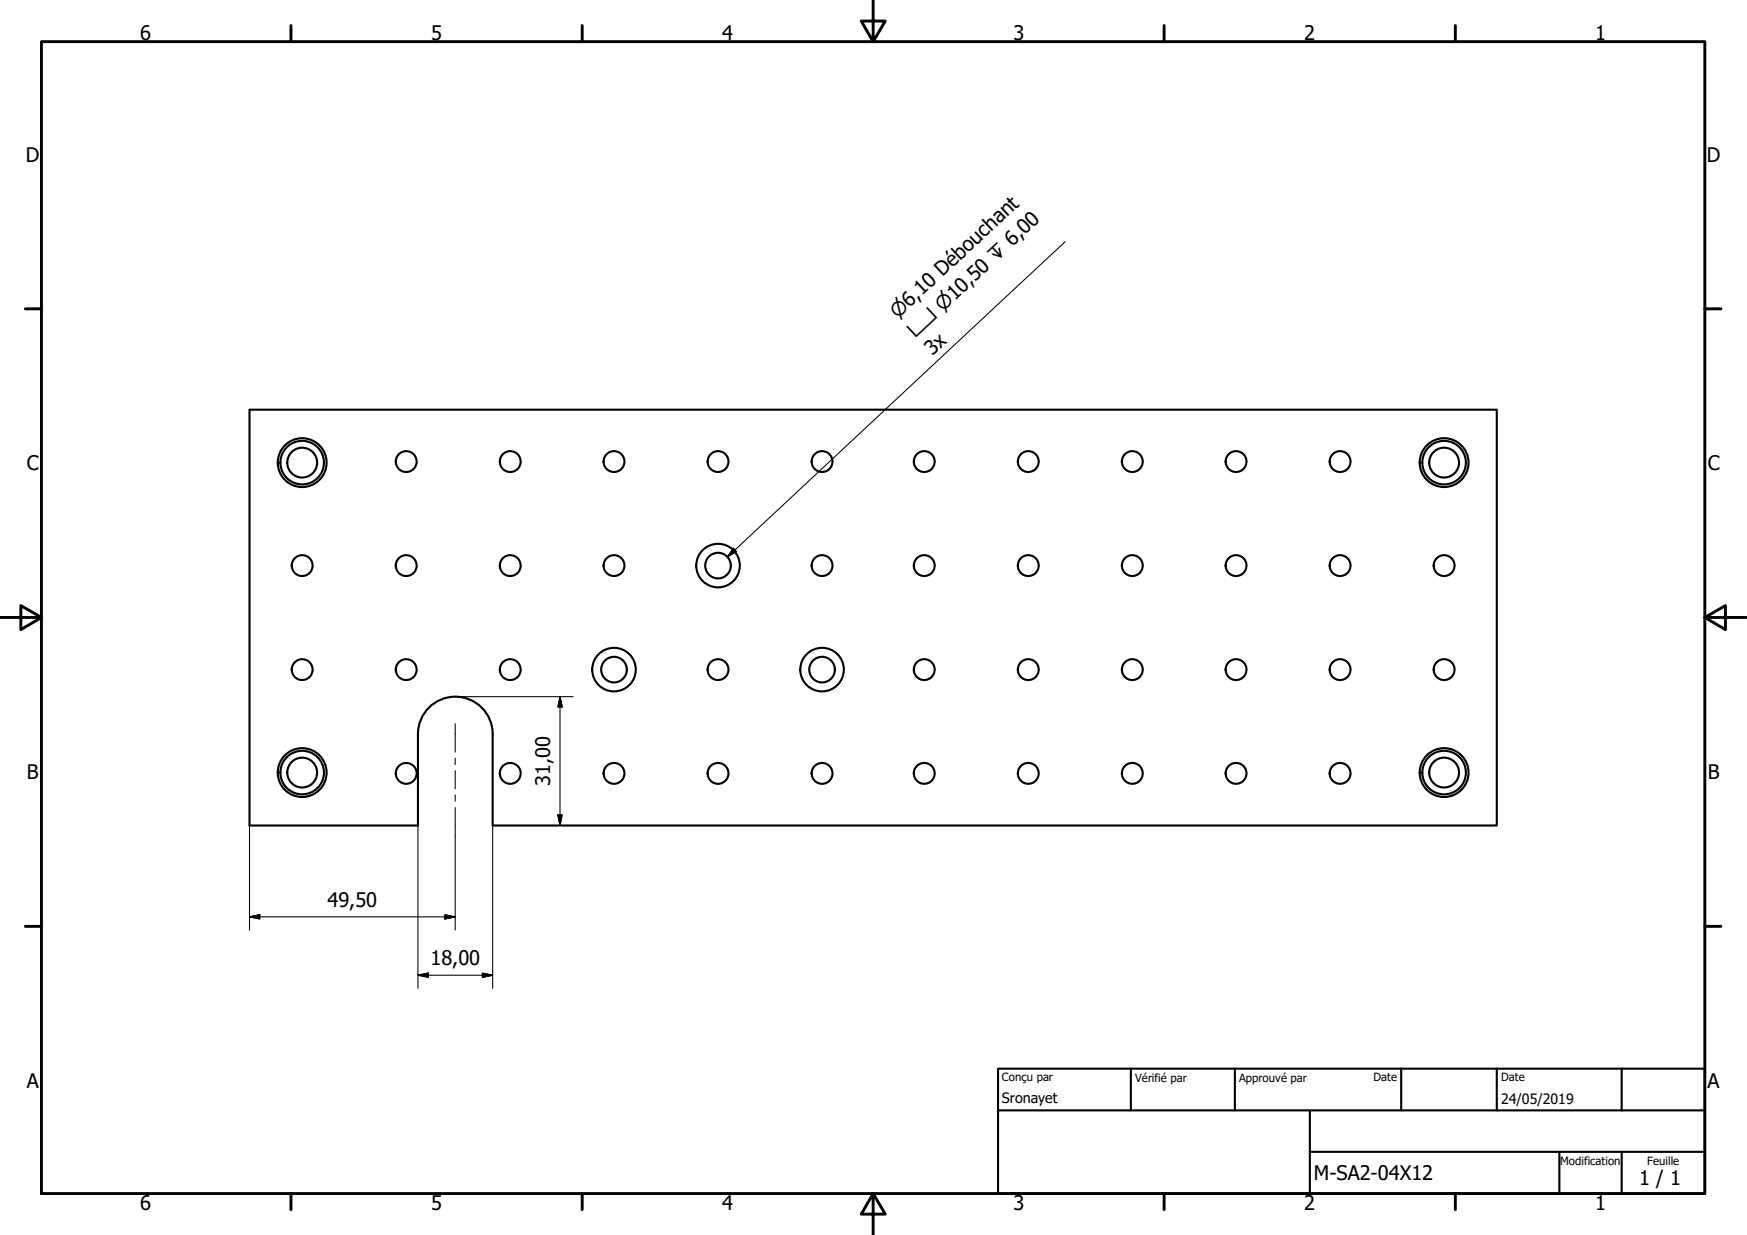
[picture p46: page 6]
Sronayet; Conou par; Vprifip par; Approuvp par; Date; 10 Dpbouchant X P10,50 Z 6,00

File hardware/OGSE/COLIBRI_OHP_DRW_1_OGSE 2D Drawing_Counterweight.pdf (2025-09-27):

A

16 | 15 | 12 | 10 | 8 | 6 | 4 14 | 11 | 9 | 7 | 5 | 3 | 2 13 | 1

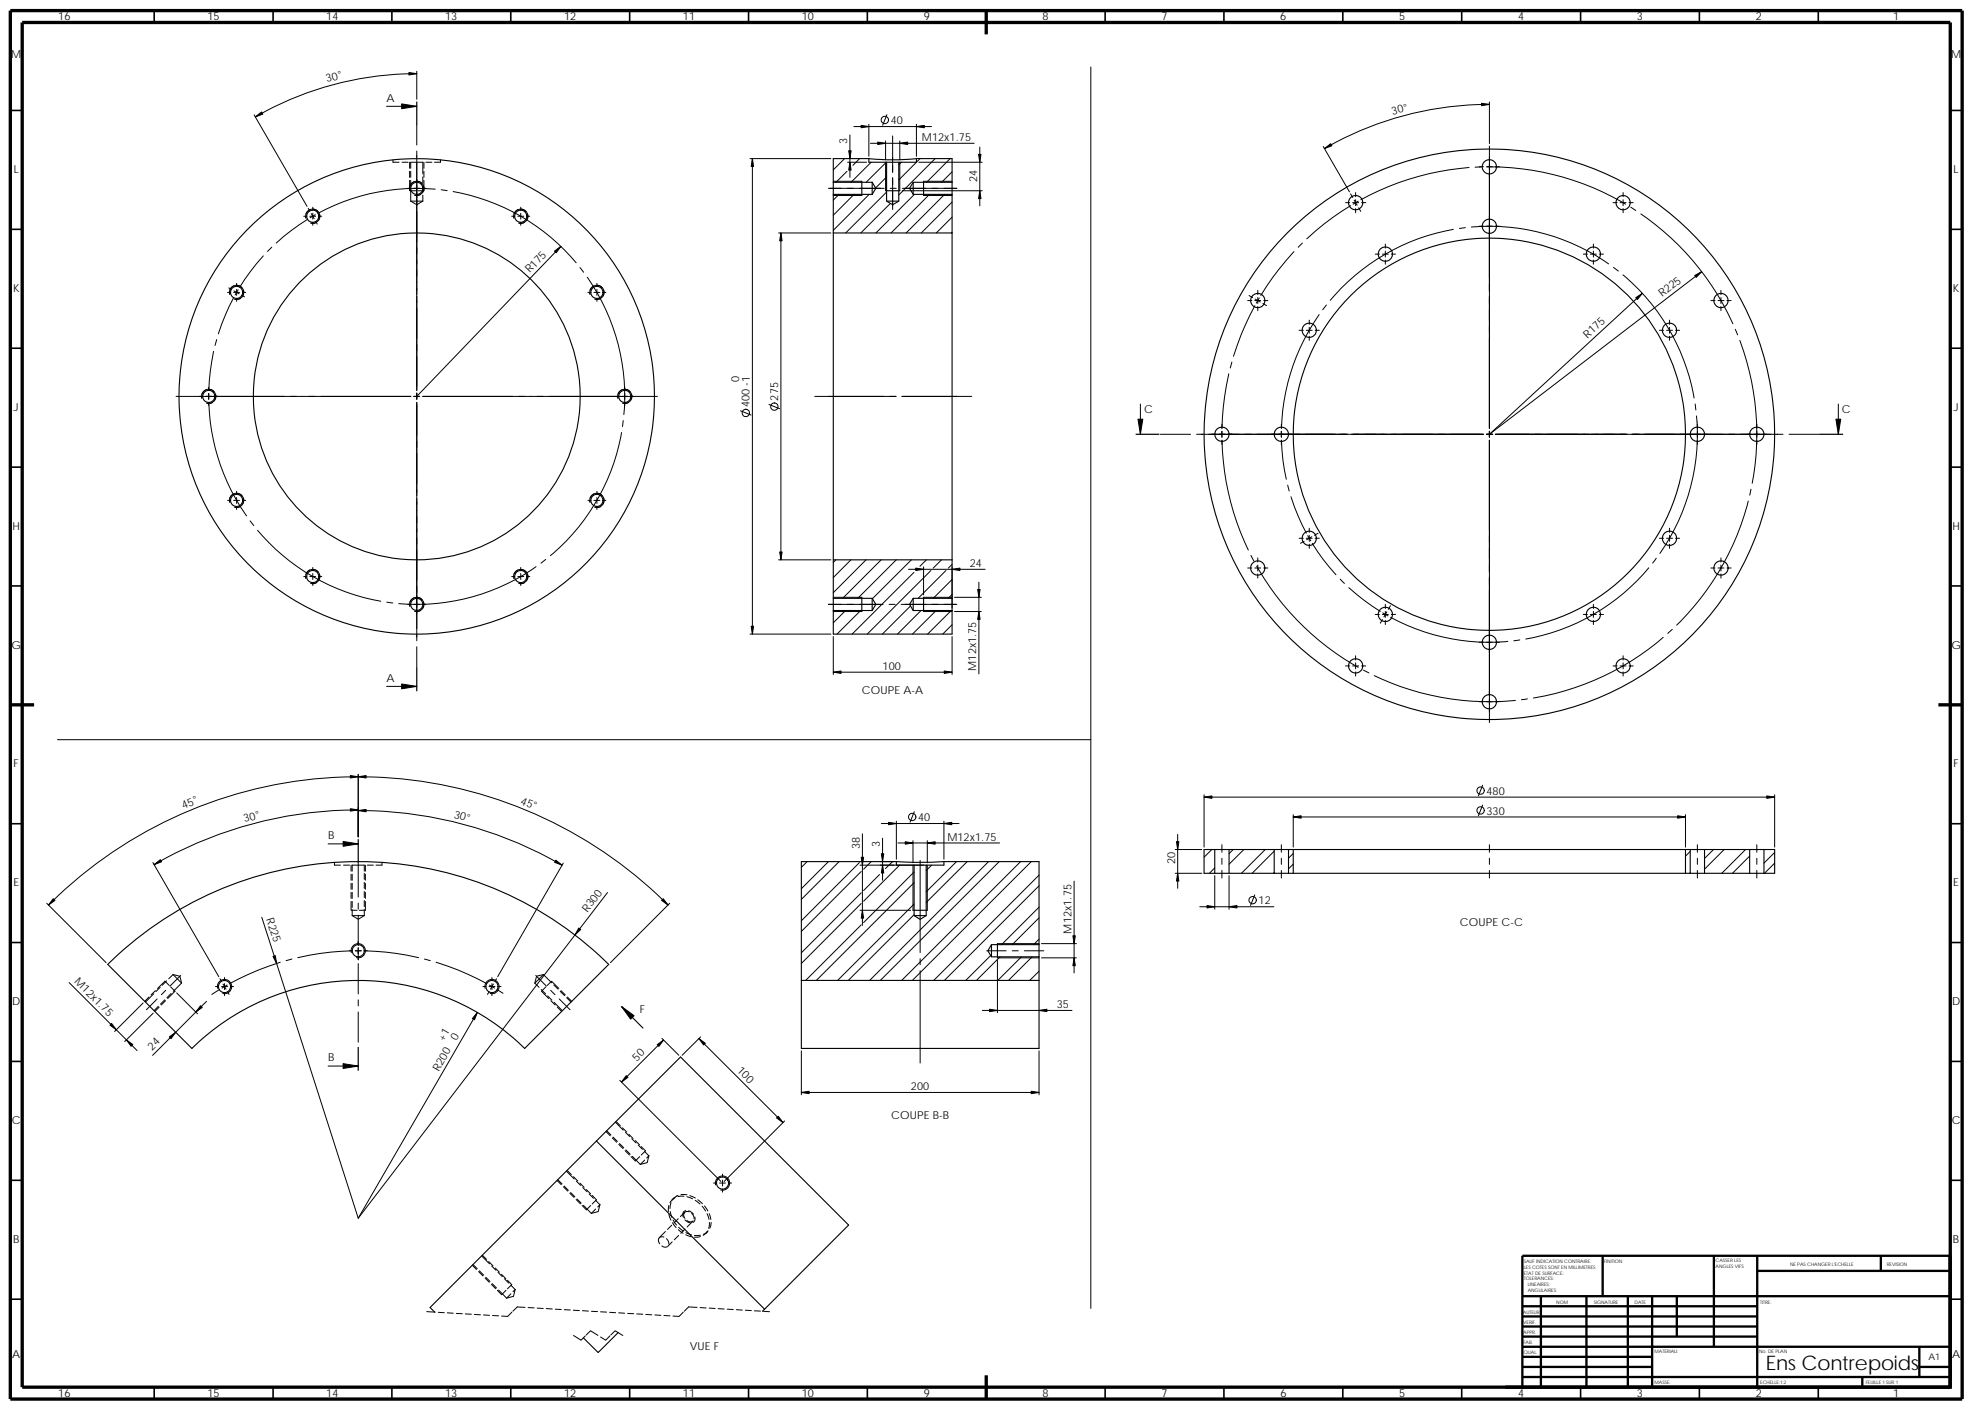
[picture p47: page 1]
REVISION; ECHELLE:1:2; FEUILLE 1 SUR 1; MASSE:; FINITION:; ANGLES VIFS; CASSER LES; COUPE A-A; COUPE C-C; VUE F; COUPE B-B

SAUF INDICATION CONTRAIRE:
LES COTES SONT EN MILLIMETRES
ETAT DE SURFACE:
TOLERANCES:
LINEAIRES:
ANGULAIRES:

NE PAS CHANGER L'ECHELLE

NOM | SIGNATURE | DATE | | | | TITRE:

AUTEUR
VERIF.
APPR.
FAB.
QUAL. | | | | MATERIAU: | No. DE PLAN Ens Contrepoids | A1

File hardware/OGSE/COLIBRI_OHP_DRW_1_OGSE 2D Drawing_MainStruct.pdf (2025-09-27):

16 | 15 | 12 | 10 | 8 | 6 | 4 14 | 11 | 9 | 7 | 5 | 3 | 2 13 | 1

M

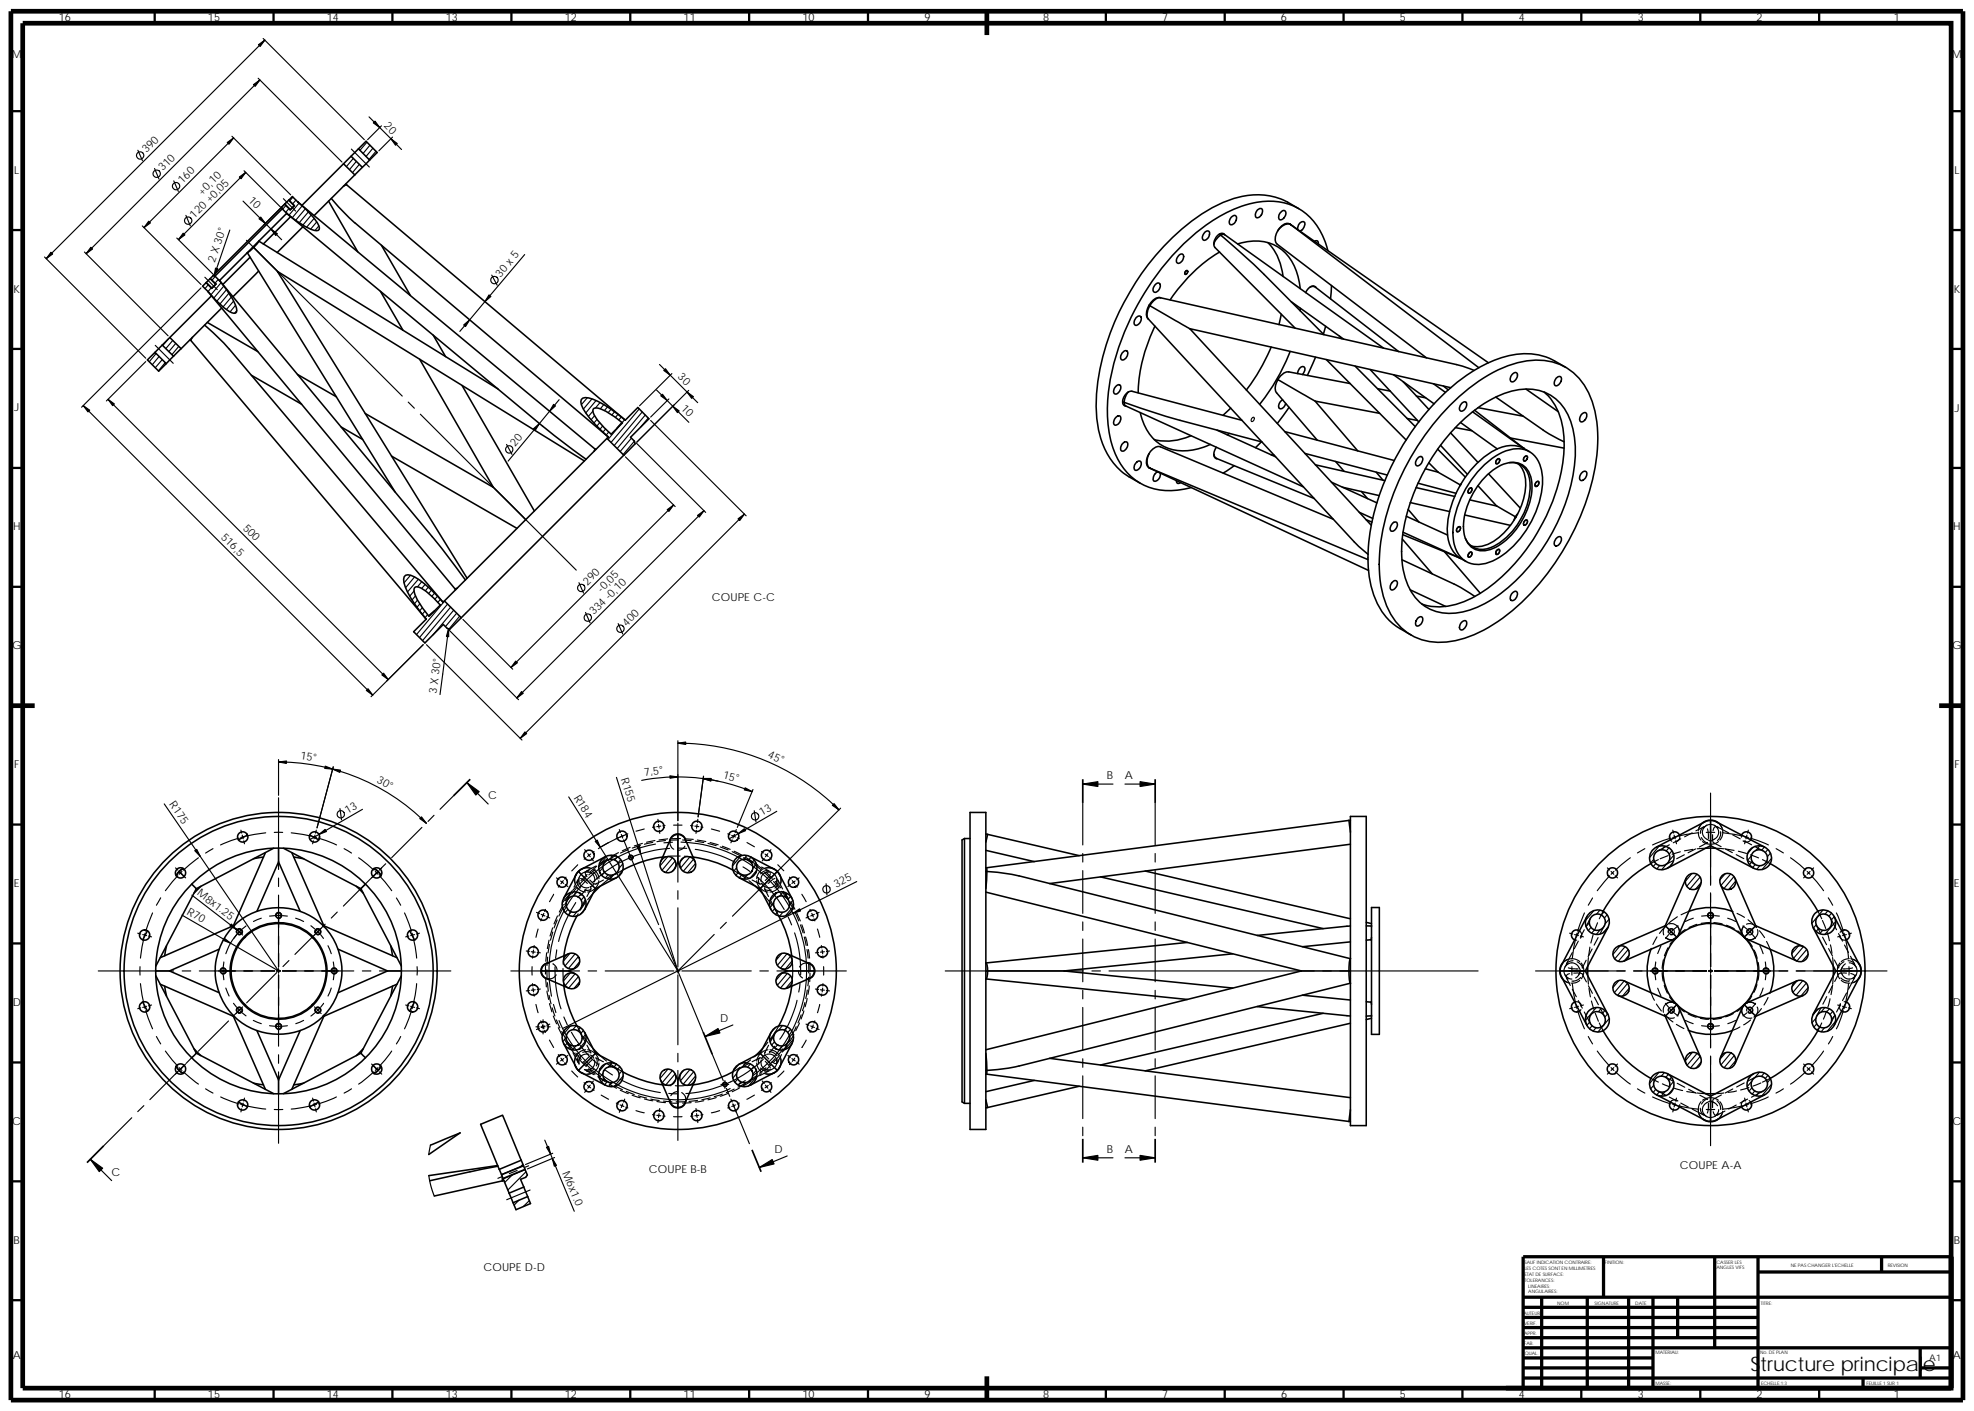
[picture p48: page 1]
COUPE C-C; COUPE B-B; COUPE A-A; COUPE D-D; ECHELLE:1:3; FEUILLE 1 SUR 1; MASSE:; NE PAS CHANGER L'ECHELLE; REVISION; FINITION:; ANGLES VIFS; CASSER LES

SAUF INDICATION CONTRAIRE:
LES COTES SONT EN MILLIMETRES
ETAT DE SURFACE:
TOLERANCES:
LINEAIRES:
ANGULAIRES:

NOM | SIGNATURE | DATE | | | | TITRE:

AUTEUR
VERIF.
APPR.
FAB.
QUAL. | | | | MATERIAU: Structure principale | No. DE PLAN | A1

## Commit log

2025-09-27 Added data and plans for Edmund Optics hardware
    [iges_11147.igs, iges_39038.igs, iges_39039.igs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]
2025-09-27 Added notes on the Baader hardware
    [2961700R.csv, 2961700R.xlsx]
2025-09-30 Added notes on work on the sensor on 2025-09-30
